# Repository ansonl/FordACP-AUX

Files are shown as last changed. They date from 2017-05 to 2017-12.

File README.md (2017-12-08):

# Ford CD changer emulator with AUX audio and stock playback control using Arduino UNO

### **Keep the retro stereo. Bring your own tunes.**

demo

Add AUX audio input to your older Ford vehicle using a Atmega328 (Arduino UNO) and use the stock radio head unit to control playback on your iPhone. 

## [Read about the development of this.](http://ansonliu.com/2017/09/ford-acp-cd-changer-emulator-aux-audio/)

  - Adapted from Dale Thomas's [*Ford Bluetooth Interface*](http://www.instructables.com/id/Ford-Bluetooth-Interface-Control-phone-with-stock-/) and Krysztof Pintscher's  [Ford CD Emulator](http://www.instructables.com/id/Ford-CD-Emulator-Arduino-Mega/).
  - Uses Ford Audio Control Protocol (ACP) to emulate stock 6 CD Changer.
  - Adds AUX audio input to vehicle.
  - Allows stock head unit playback control of iPhone.
  - Protoshield hand wiring diagram included in `Resources` folder. 
  - EAGLE PCB files in `eagle` folder.

### Directions
  - Open **Ford_ACP_AUX.ino** located in *Sketch/Ford_ACP_AUX* and upload to Arduino UNO.
  - Acquire parts on Bill of Materials located in *Resources/LIU_FORD_ACP_AUX_BOM.xlsx*.
  - Do one of the following
    1. Wire up Arduino UNO like shown below. *Note: Updated pin 8 → pin 7 in latest code.*
    2. Print PCB using provided EAGLE files.
  - Place the assembly in your car.

#### BLE vehicle lock/unlock.
  - Follow directions above but use **Ford_AUX_BLE_control.ino** located in *Sketch/Ford_AUX_BLE_control* and upload to Arduino UNO.
  - Build and install [ansonl/ble-control](https://github.com/ansonl/ble-control) on your iOS device.

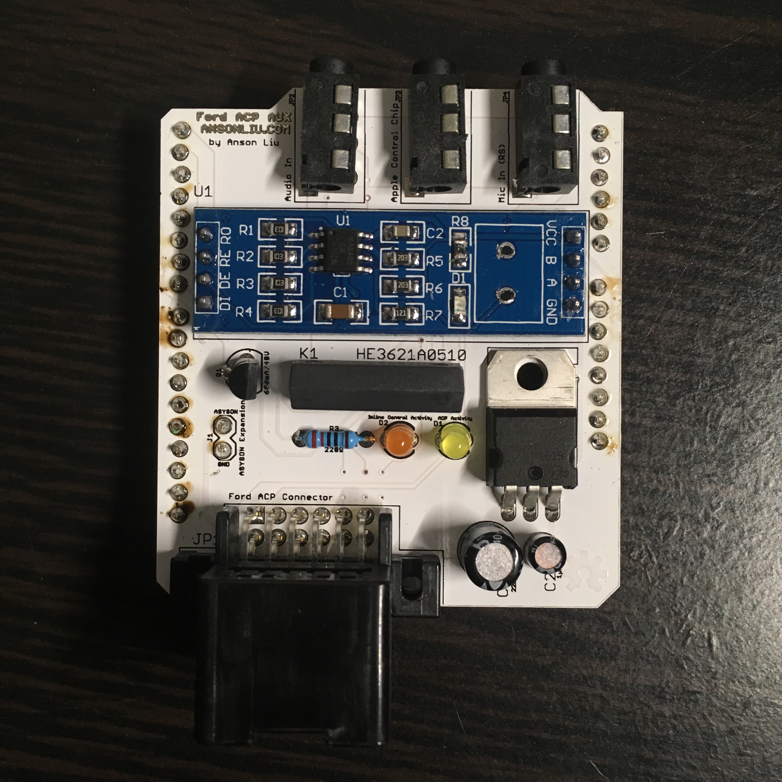
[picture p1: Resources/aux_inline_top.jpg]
PCB top

closing glovebox

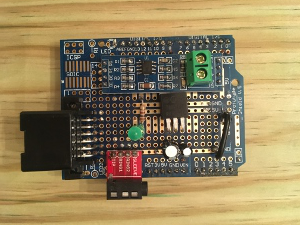
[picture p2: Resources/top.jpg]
top
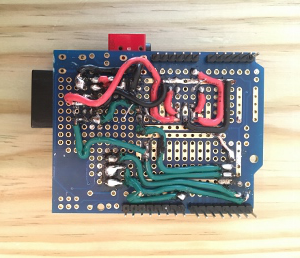
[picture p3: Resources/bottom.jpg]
bottom
 
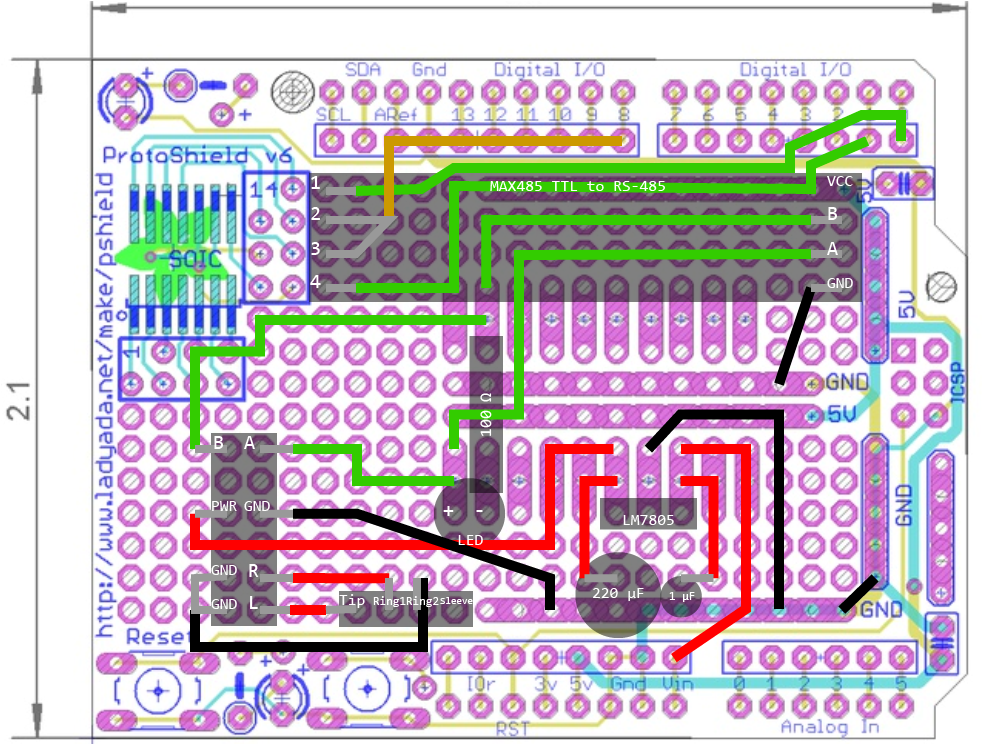
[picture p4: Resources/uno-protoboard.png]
uno protoboard

*Please note that pin 8 in the above diagram has been changed to pin 7 in the latest Ford_AUX_BLE code.* 

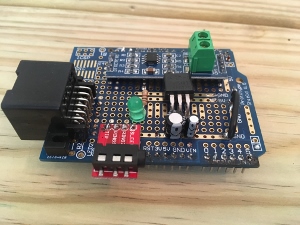
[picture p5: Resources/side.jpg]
side
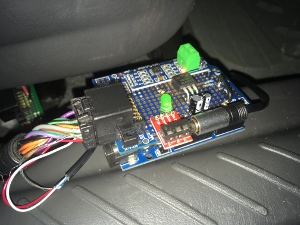
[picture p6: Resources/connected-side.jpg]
connected side
 

#### ACP Data Logging and LCD Graphing
  - Use **Ford_LCD_datagraph.ino** located in *Sketch/Ford_LCD_datagraph*.

acp visualizer

### Contributing

Please report issues and submit pull requests as needed. Please make an issue for soldering or build issues, too. 

I have resolved several people's build issues by email and someone may find your issue helpful!

### License

Any adaptation of this work must comply with licenses of previous works (those in `Resources` folder) and include references to the previous authors. 

**Any work by Anson Liu in this repository is under MIT License.**

  - Andrew Hammond
  - [Krysztof Pintscher](http://www.instructables.com/id/Ford-CD-Emulator-Arduino-Mega/)
  - [Dale Thomas](http://www.instructables.com/id/Ford-Bluetooth-Interface-Control-phone-with-stock-/)
  - [Anson Liu](http://ansonliu.com)

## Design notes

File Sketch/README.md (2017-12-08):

# See below for description of each Sketch.

####  Please note the updated pin assignments in the code before soldering.

Sketch directory | Description
--- | ---
EEPROM_test | Tests writing and reading constants in EEPROM.
**Ford_ACP_AUX** | **Standalone code for ACP CD changer emulation and inline playback control. *Latest!***
Ford_ANCS | Old sketch demonstrating ANCS integration with an LCD. Incorporates scrolling text for notifications. 
**Ford_AUX_BLE_control** | **ACP CD changer emulation and inline playback control. Use with [anson/BLE-control](https://github.com/ansonl/BLE-control). *Latest!***
Ford_LCD_datagraph | Debug sketch for graphing ACP data on a Hitachi HD44780 4x16 display. 
Ford_SD_ACP_datalogger | Debug sketch for logging ACP data to SD card using SD shield.
Ford_SD_datalogger | Debug sketch
Ford_Uno | Initial converted version of Dale Thomas' Arduino code to run on Arduino Uno.

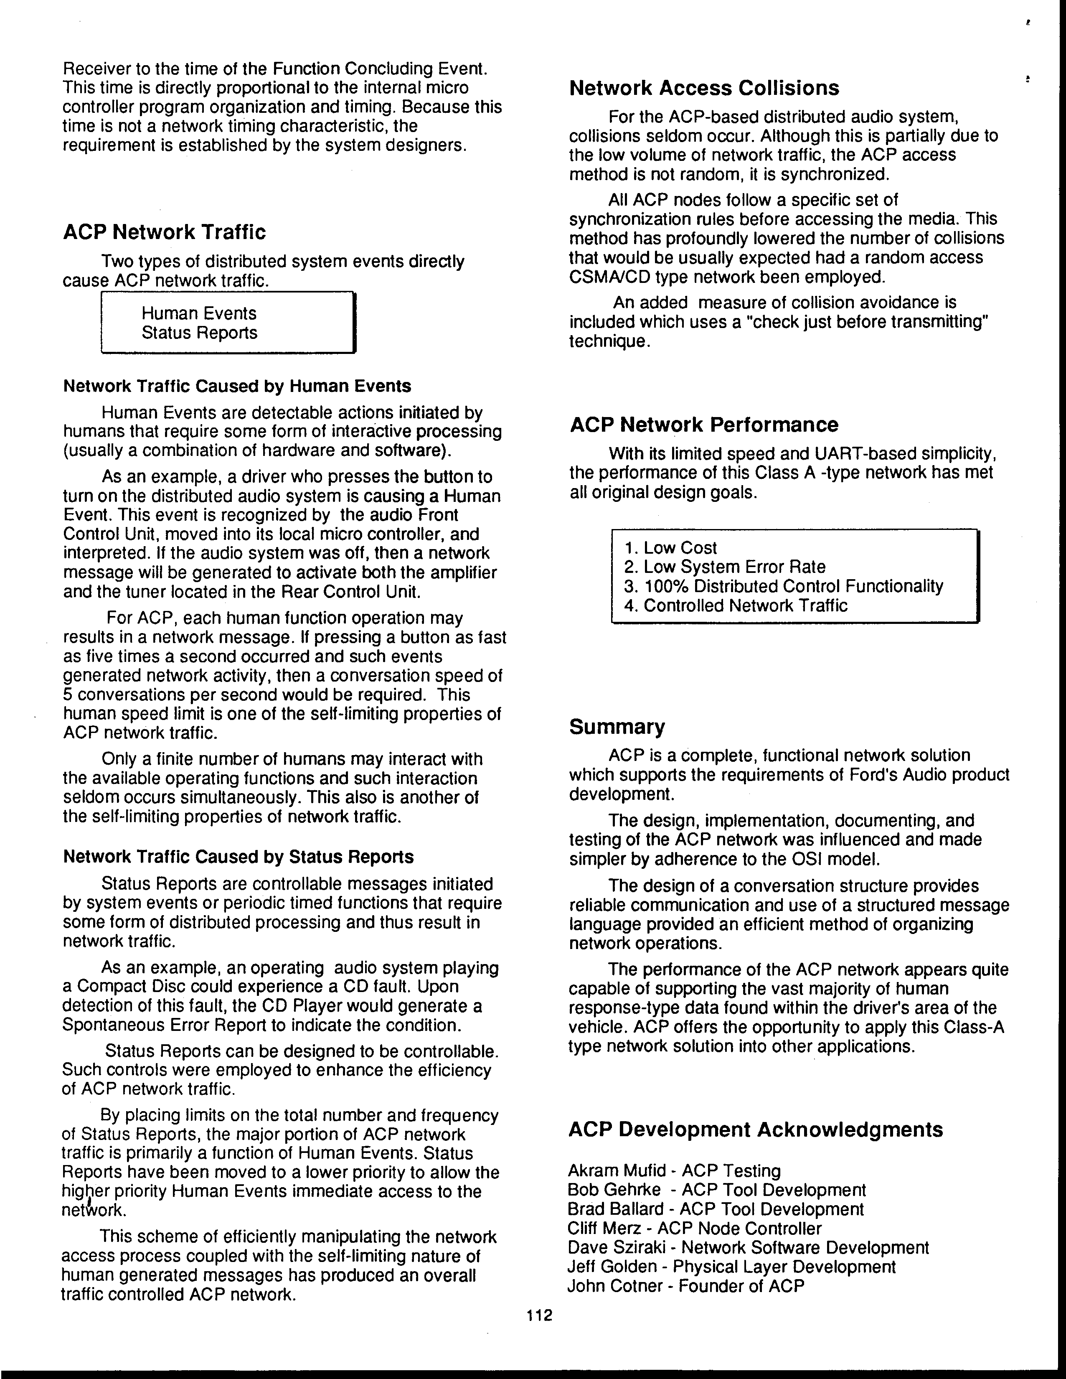
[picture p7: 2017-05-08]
Resources/Ford Bluetooth Interface V1.0 - Dale Thomas/Misc Documents/Misc Documents/Misc Documents/ACP/FORDs_ACP_Protocol/page18.bmp

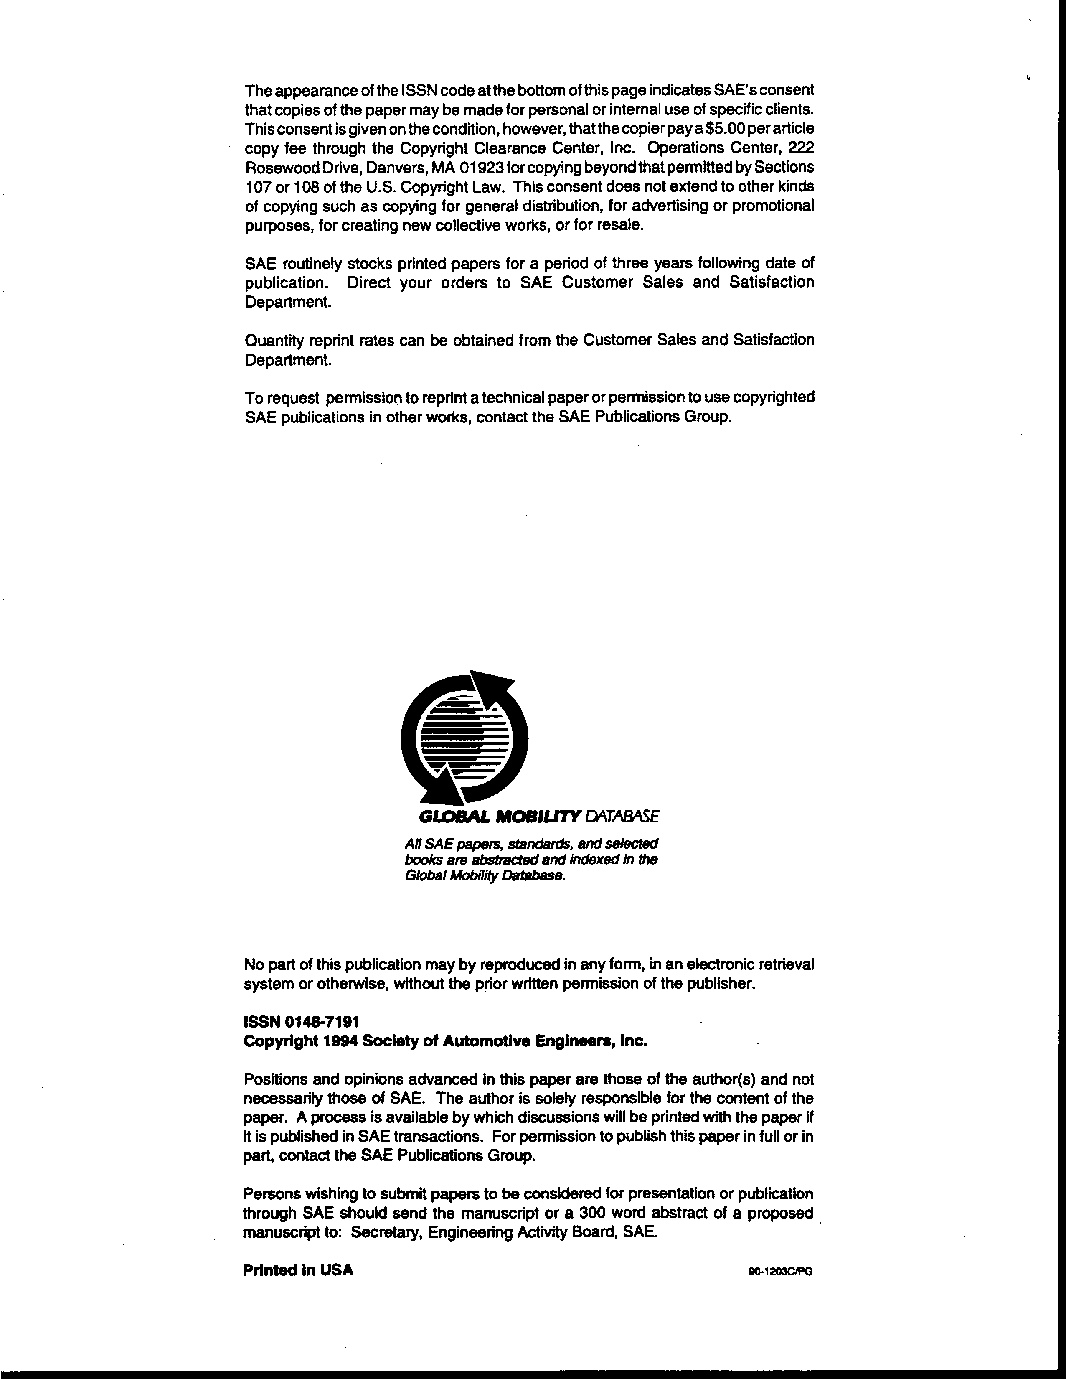
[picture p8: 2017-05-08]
Resources/Ford Bluetooth Interface V1.0 - Dale Thomas/Misc Documents/Misc Documents/Misc Documents/ACP/FORDs_ACP_Protocol/page02.bmp

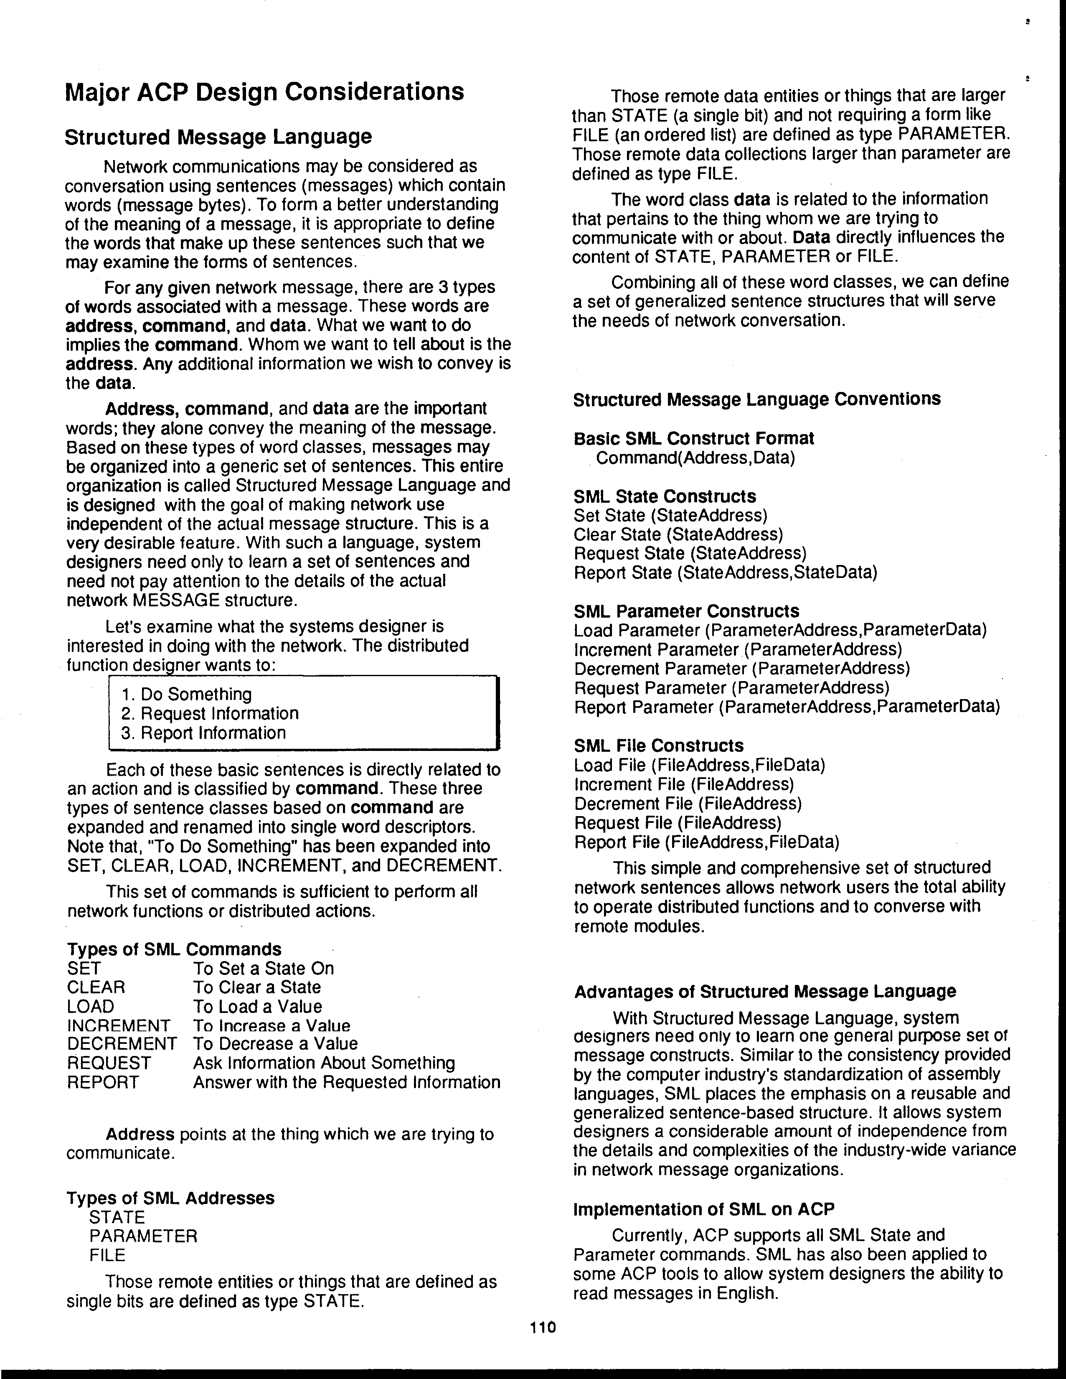
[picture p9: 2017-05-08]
Resources/Ford Bluetooth Interface V1.0 - Dale Thomas/Misc Documents/Misc Documents/Misc Documents/ACP/FORDs_ACP_Protocol/page16.bmp

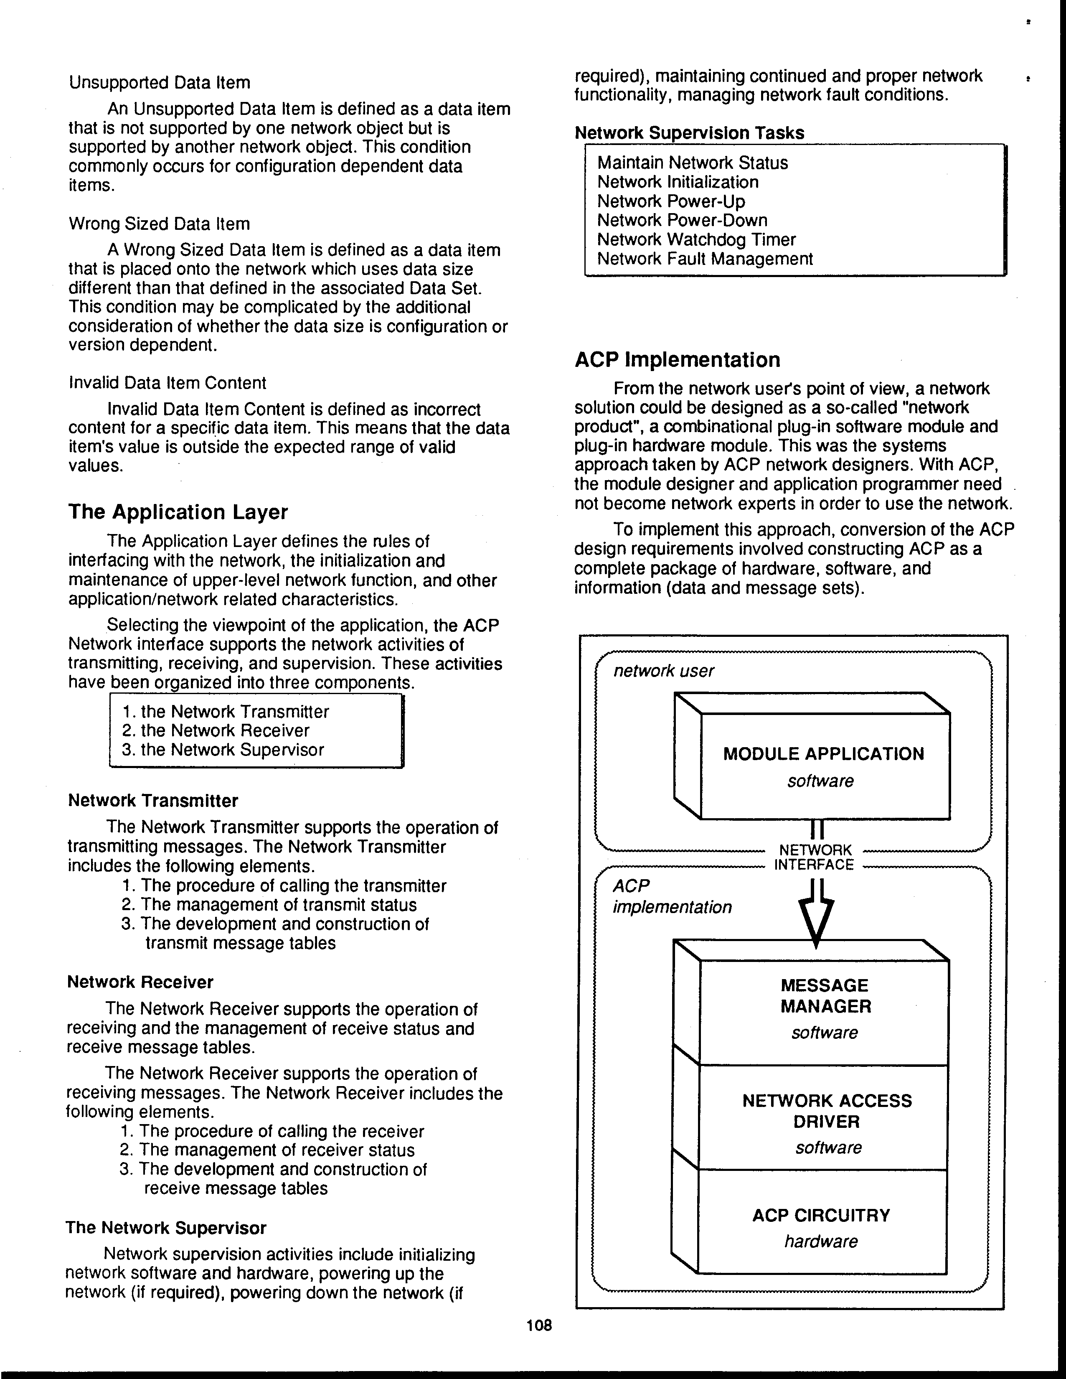
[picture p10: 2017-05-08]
Resources/Ford Bluetooth Interface V1.0 - Dale Thomas/Misc Documents/Misc Documents/Misc Documents/ACP/FORDs_ACP_Protocol/page14.bmp

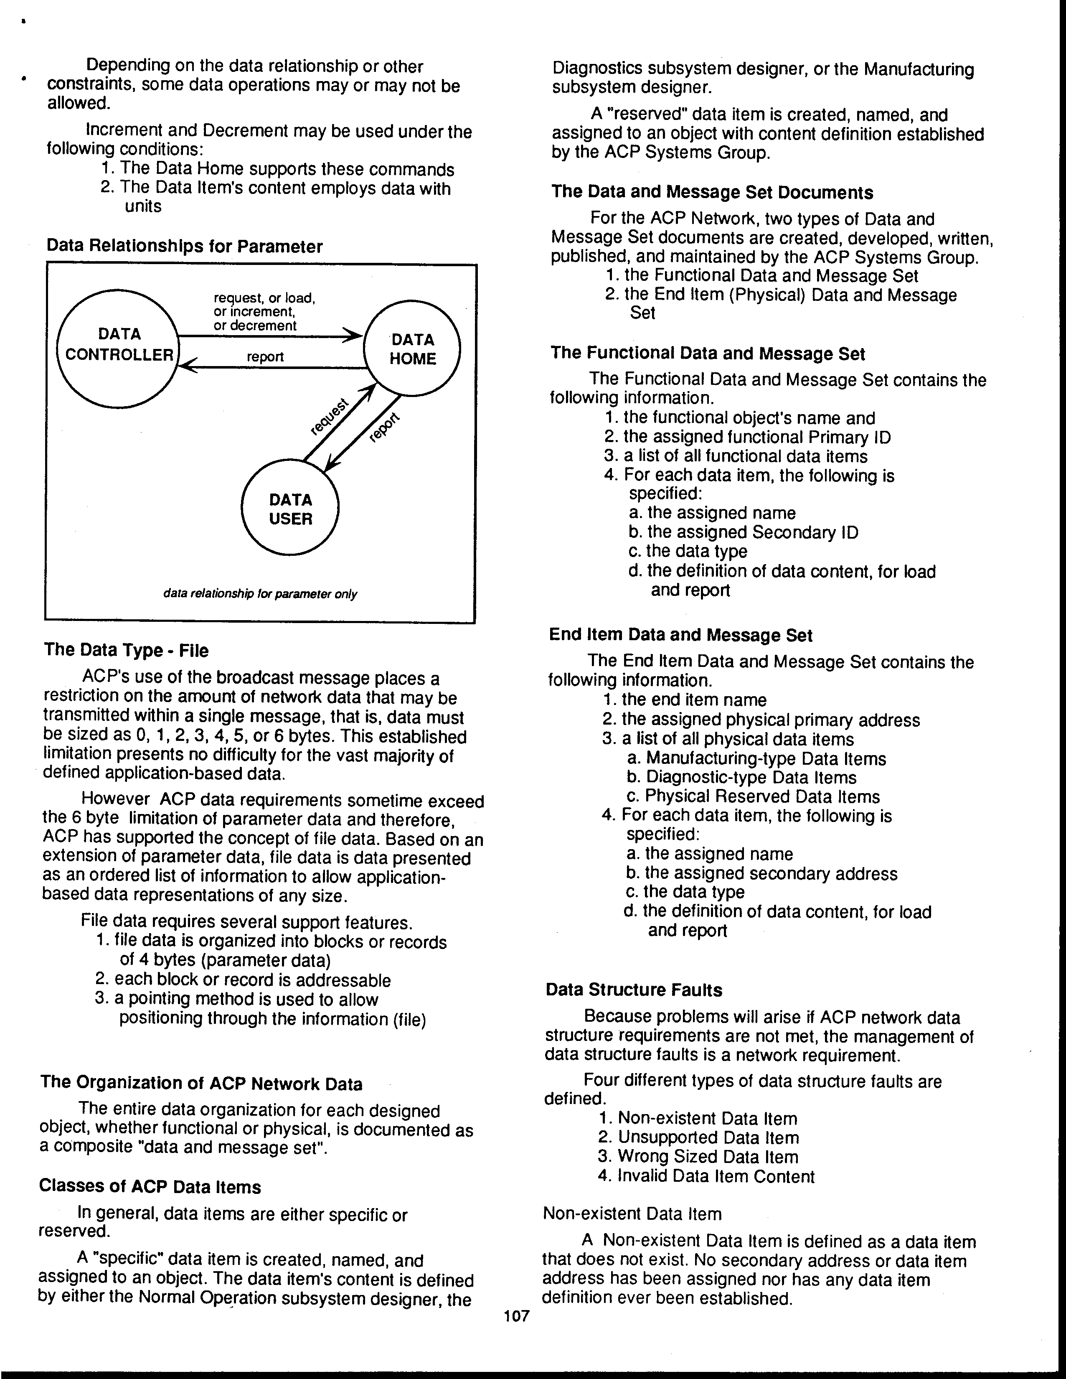
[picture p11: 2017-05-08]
Resources/Ford Bluetooth Interface V1.0 - Dale Thomas/Misc Documents/Misc Documents/Misc Documents/ACP/FORDs_ACP_Protocol/page13.bmp

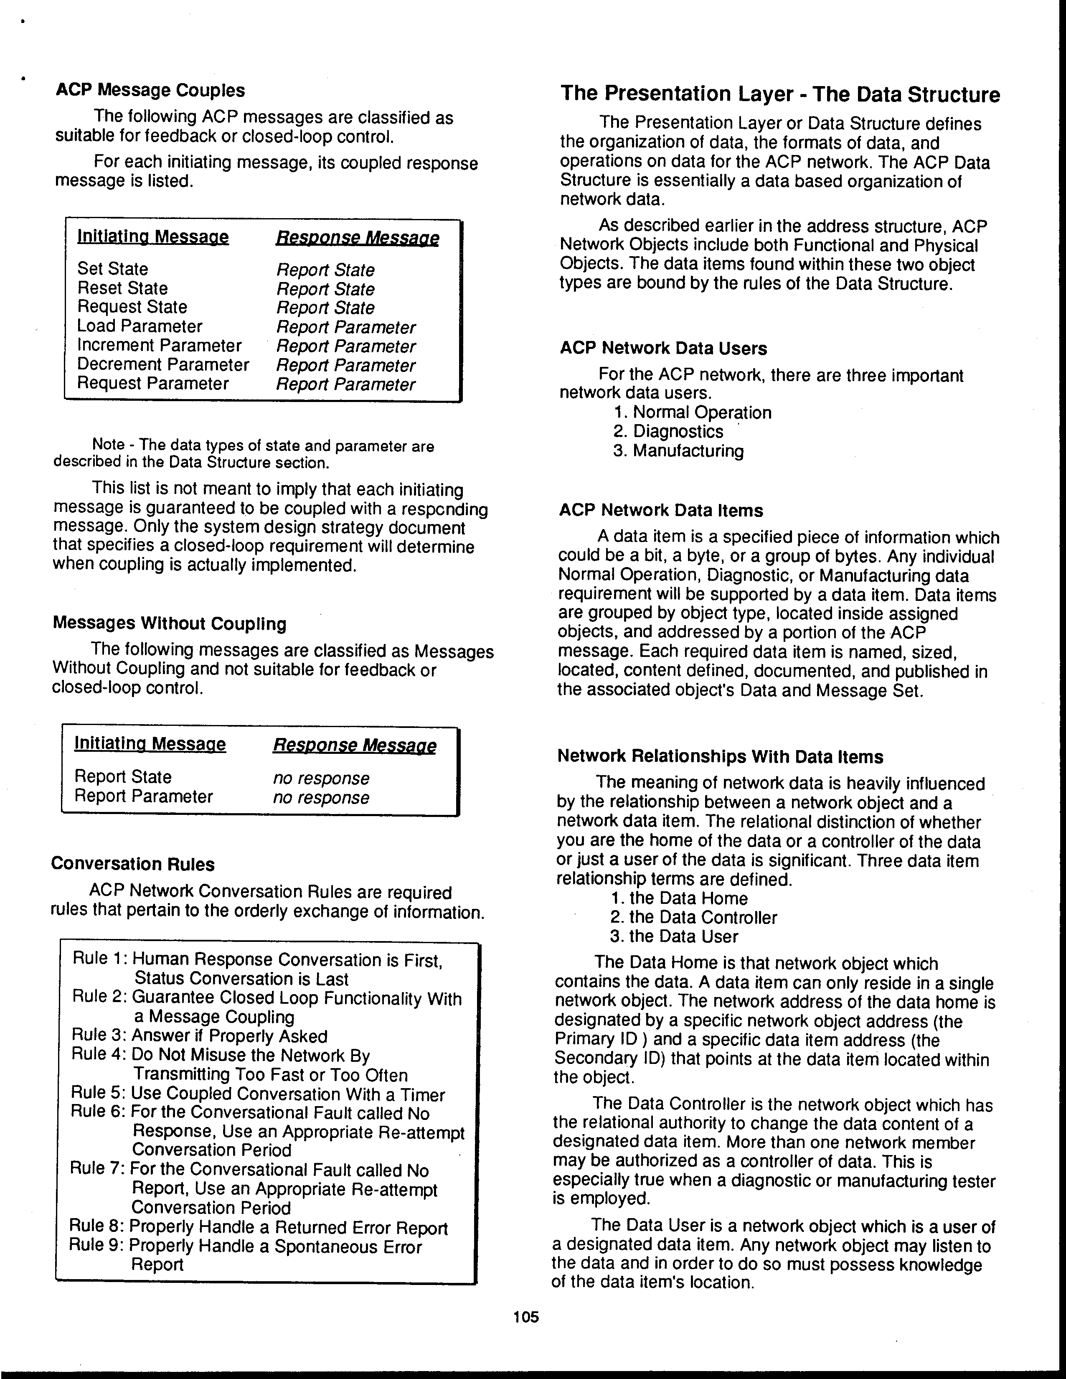
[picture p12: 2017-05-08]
Resources/Ford Bluetooth Interface V1.0 - Dale Thomas/Misc Documents/Misc Documents/Misc Documents/ACP/FORDs_ACP_Protocol/page11.bmp

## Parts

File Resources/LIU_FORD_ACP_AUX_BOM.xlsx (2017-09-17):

Alias | Description | Supplier | Suppliers Part # | Manufacturers Part # | Quantity | Cost Each | Total Cost
 | Arduino UNO | Ebay |  |  | 1 | $5.00 | $5.00
B1 | Arduino UNO size shield or Ford ACP AUX PCB | Ebay/Other |  |  | 1 | $2.00 | $2.00
 | 2.54mm Breakout board stackable headers, 12pins | Tayda |  |  | 4 | $0.22 | $0.88
JP1 | Series 40 locking connector (Female, wire-to-board) | Mouser | 571-174051-2 | 174051-2 | 1 | $5.00 | $5.00
IC1 | LM7805 5V voltage regulator | Tayda |  |  | 1 | $0.23 | $0.23
C1 | 220 uF filter capacitor, electrolytic | Tayda |  |  | 1 | $0.03 | $0.03
C2 | 1 uF filter capacitor, electrolytic | Tayda |  |  | 1 | $0.02 | $0.02
U1 | (Max485) TTL to RS485 converter breakout board | Ebay |  |  | 1 | $0.50 | $0.50
D1 | 5mm LED (ACP activity indicator) | Tayda |  |  | 1 | $0.02 | $0.02
JP1 JP2 JP3 | 3.5mm 4-pole TRRS Cellphone Headphone Jack PCB mount | mklec | 83-176-1245 | 3.5MM4POLEJACK | 3 | $0.40 | $1.20
Q1 | 2N2222 NPN transistor | Tayda |  |  | 1 | $0.02 | $0.02
K1 | LITTLEFUSE Reed relay w/ diode supressed coil | Arrow |  | HE3621A0510 | 1 | $1.00 | $1.00
R3 | 220 ohm resistor 1/4W | Tayda |  |  | 1 | $0.02 | $0.02
D2 | 5mm LED (Inline control activity indicator) | Tayda |  |  | 1 | $0.02 | $0.02
optional, for wiring | 4 Conductor Metal 3.5 Female to Female Ground Isolated Feed-thru Jack | Markertek |  | 30-707 | 1 | $4.82 | $4.82
optional, for wiring | 3.5mm TRRS cable, 3ft | Monoprice |  | 18632 | 2 | $2.00 | $4.00
optional, for wiring | Series 40 locking connector (Male, wire-to-wire) | Arrow |  | TE 174045-2 | 2 |  | $0.00
optional, for wiring | Series 40 locking connector (Female, wire-to-wire) | Arrow |  | TE 174058-2 | 1 |  | $0.00
optional, for wiring | Series 40 locking connector (For TE 174045-2) | Arrow |  | TE 175180-1 | 24 |  | $0.00
optional, for wiring | Series 40 locking connector (For TE 174058-2) | Arrow |  | TE 175182-1 | 12 |  | $0.00
 |  |  |  |  |  |  | $24.76
 |  |  |  |  |  | Total: | $0.00

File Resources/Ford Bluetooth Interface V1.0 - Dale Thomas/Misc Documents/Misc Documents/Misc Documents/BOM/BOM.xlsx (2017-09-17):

Alias | Description | Supplier | Suppliers Part # | Manufacturers Part # | Quantity | Last Cost Each | Total Cost
DIS_1 | 1602 16x2 HD44780 Character LCD Display Module LCM Yellow Blacklight | eBay |  | HD44780 | 1 | $3.33 | $3.33
MCU_1 | ATmega2560-16AU CH340G MEGA 2560 R3 Board + Free USB Cable for Arduino | eBay |  |  | 1 | $13.85 | $13.85
BLT_1 | BLK-MD-SPK-B bluetooth breakout board for the OVC 3860 | eBay |  | BLK-MD-SPK-B | 1 | $6.89 | $6.89
MIC_1 | Mini 2 Pin 53-54 DB 9.7mm*6.7mm Electret Microphone Pickup Condenser | eBay |  |  | 1 | $0.19 | $0.19
U_1 | TLP250 optical isolator | eBay |  | TLP250 | 1 | $1.00 | $1.00
U_2 | Max 485 ttl to RS485 converter | eBay |  | MAX485 | 1 | $2.20 | $2.20
U_3 | LM7805 5V voltage regulator | eBay |  | LM7805 | 1 | $0.39 | $0.39
CON_1 | Series 40 locking connector | Mouser | 571-174051-2 | 174051-2 | 1 | $2.45 | $2.45
CON_2, CON_3 | 40-Pin 2.54mm Straight Female Header | eBay |  |  | 2 | $0.10 | $0.20
CON_4 | Amico DIP PCB Mount 11 Pins Female 3.5mm Stereo Audio Jack Socket | eBay |  |  | 1 | $1.39 | $1.39
PCB_1 | Prototype PCB for Arduino Mega 2560 R3 Shield Board | eBay |  |  | 1 | $2.20 | $2.20
PCB_2 | Bluetooth BLK-MD-SPK-B Stereo Module Breakout board | eBay |  |  | 1 | $4.00 | $4.00
POT_1 | 1000 ohm potentiometer | eBay |  |  | 1 | $0.17 | $0.17
D_1 | Red LED | eBay |  |  | 1 | $0.03 | $0.03
D_2 | Blue LED | eBay |  |  | 1 | $0.03 | $0.03
D_3 | Green LED | eBay |  |  | 1 | $0.03 | $0.03
R_1, R_2 | 500 ohm resistor | eBay |  |  | 2 | $0.01 | $0.02
R_3, R_5, R_6 | 10000 ohm resistor | eBay |  |  | 3 | $0.01 | $0.03
R_4 | 2700 ohm resistor | eBay |  |  | 1 | $0.01 | $0.01
L_1 | 15 nH inductor | eBay |  |  | 1 | $0.10 | $0.10
C_1 | 4.7 uF capacitor | eBay |  |  | 1 | $0.10 | $0.10
C_2 | 10 pF capacitor | eBay |  |  | 1 | $0.10 | $0.10
C_3 | 1 uF | eBay |  |  | 1 | $0.10 | $0.10
C_4 | 220 uF filter capacitor, electrolytic | eBay |  |  | 1 | $0.10 | $0.10
C_5 | 1 uF filter capacitor, electrolytic | eBay |  |  | 1 | $0.10 | $0.10
 |  |  |  |  |  | Total: | $39.01

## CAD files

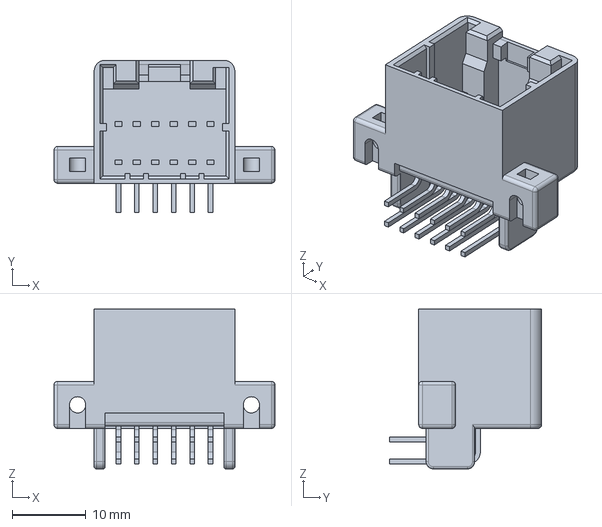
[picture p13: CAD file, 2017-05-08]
Resources/Ford Bluetooth Interface V1.0 - Dale Thomas/Misc Documents/Misc Documents/Misc Documents/Radio Connectors/Connectors/c-174051-2-k-3d.stp
30.0 x 20.7 x 21.7 mm

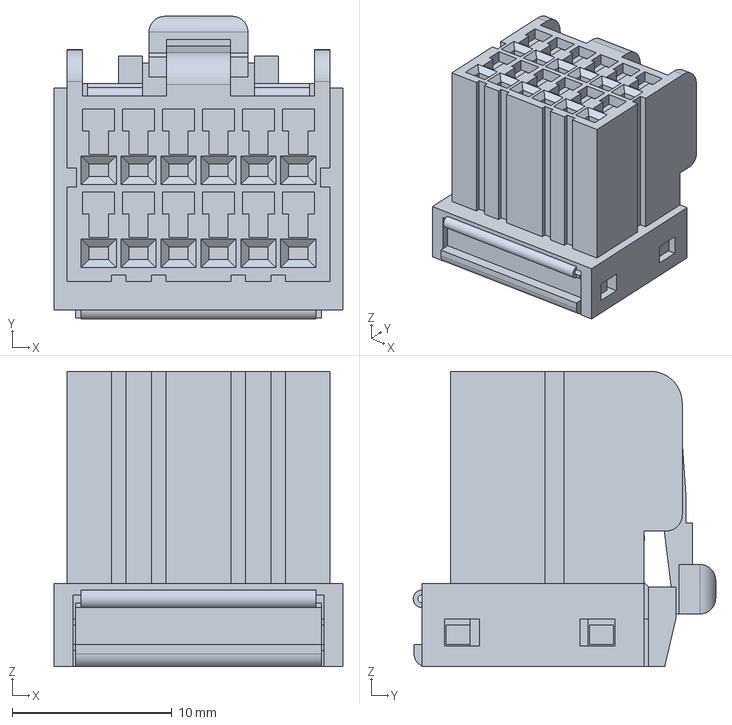
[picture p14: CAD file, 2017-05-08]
Resources/Ford Bluetooth Interface V1.0 - Dale Thomas/Misc Documents/Misc Documents/Misc Documents/Radio Connectors/Connectors/c-174045-2-c1-3d.stp
18.1 x 19.0 x 18.5 mm

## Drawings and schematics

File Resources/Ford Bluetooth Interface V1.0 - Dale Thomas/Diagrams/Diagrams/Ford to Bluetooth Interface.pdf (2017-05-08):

# Ford Bluetooth Interface

V 1.0

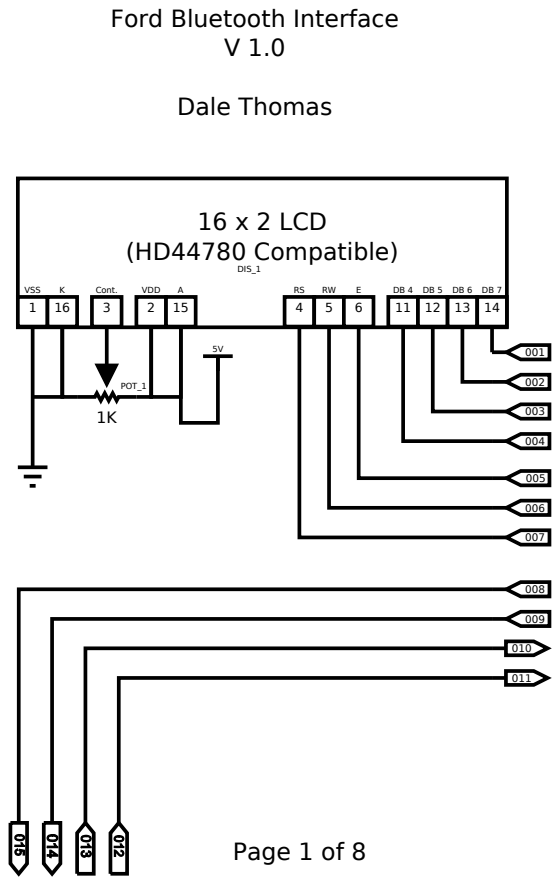
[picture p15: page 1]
VSS; VDDCont.; 16 x 2 LCD (HD44780 Compatible); Page 1 of 8; Dale Thomas; DIS_1; POT_1

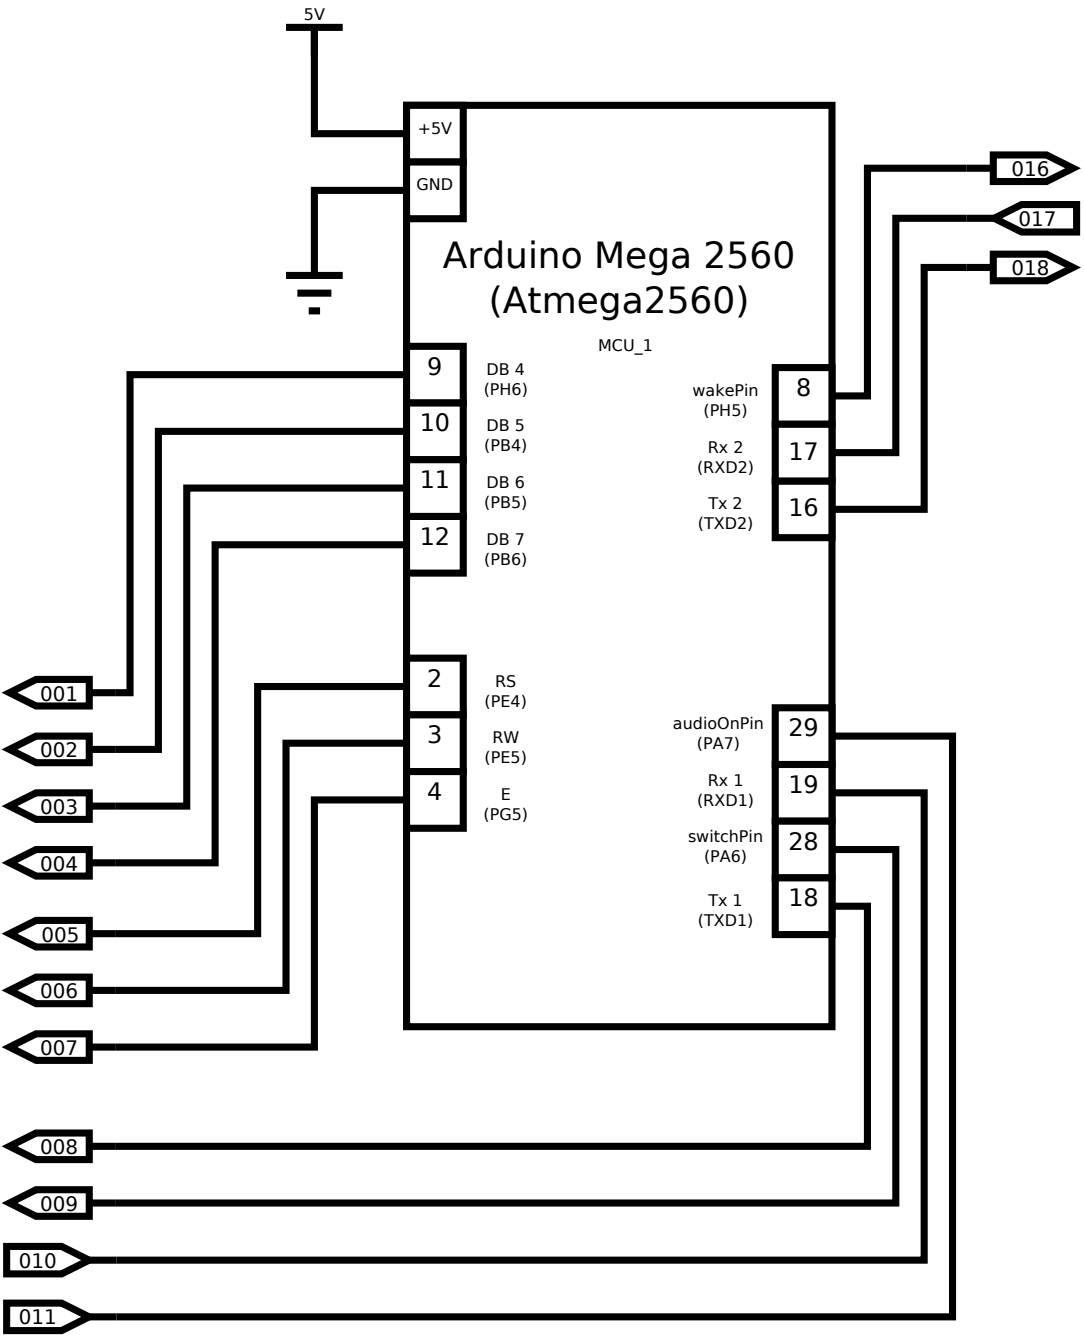
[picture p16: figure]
wakePin (PH5); switchPin; audioOnPin; Tx 2 (TXD2); Rx 2 (RXD2); (TXD1); (RXD1); Arduino Mega 2560 (Atmega2560); GND; MCU_1

# Page 2 of 8

016

017

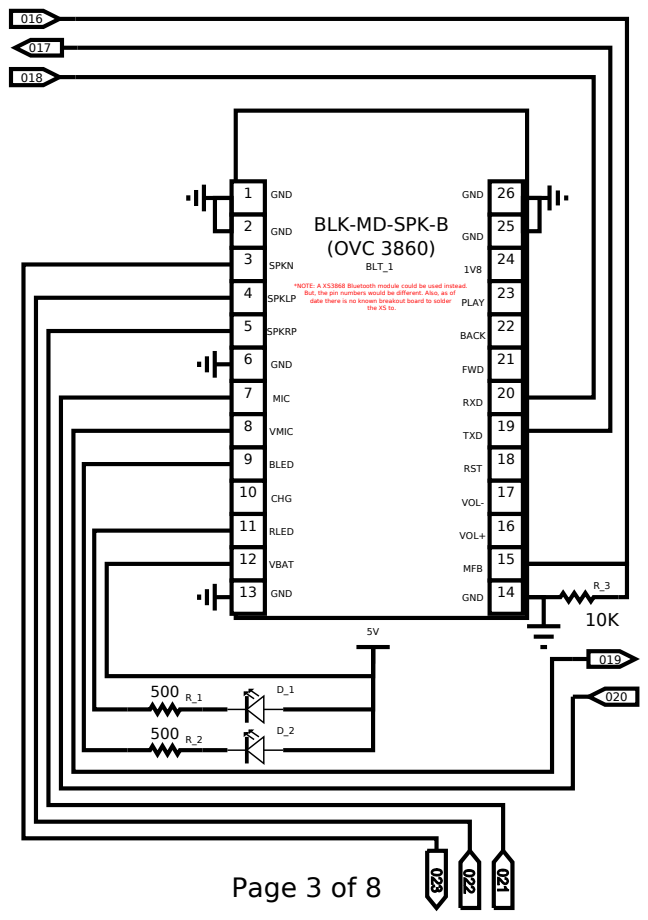
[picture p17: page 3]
1 GND; 2 GND; 3 SPKN; 4 SPKLP; 5 SPKRP; 6 GND; MIC; 8 VMIC; 9 BLED; 10 CHG; 11 RLED; 12 VBAT; 13 GND; GND; PLAY; BACK; FWD; RXD; TXD; RST; VOL-; VOL+; MFB; Page 3 of 8; BLT_1

BLK-MD-SPK-B
(OVC 3860)

*NOTE: A XS3868 Bluetooth module could be used instead.
But, the pin numbers would be different. Also, as of
date there is no known breakout board to solder

the XS to.

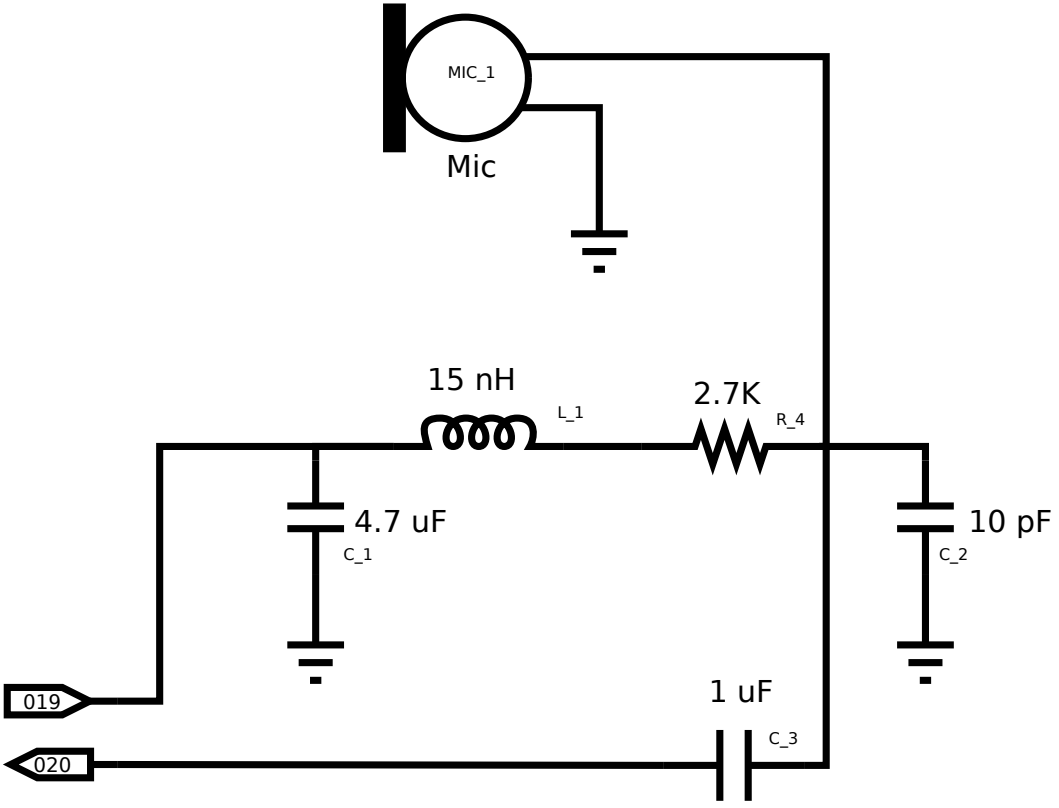
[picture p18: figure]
Mic; MIC_1

# Page 4 of 8

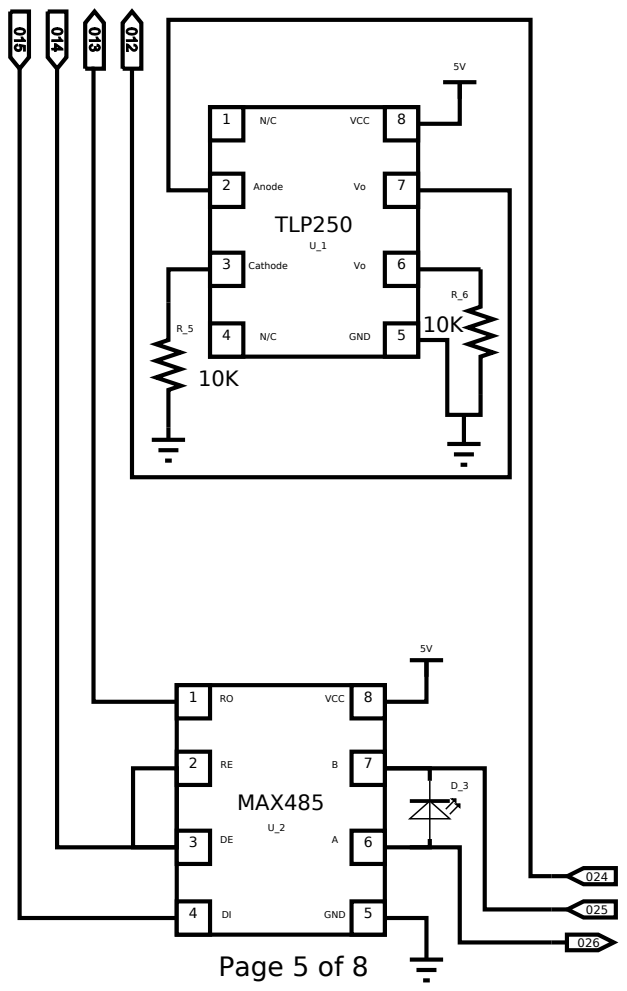
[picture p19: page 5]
VCC; GND; 3 Cathode; Anode; TLP250; MAX485; Page 5 of 8

LM7805

IN | OUTGND
5V
1 | 2 | 3

# Page 6 of 8

024

025

026

027

028

029

030

# 220 uF 1 uF

U_3

C_4 | C_5

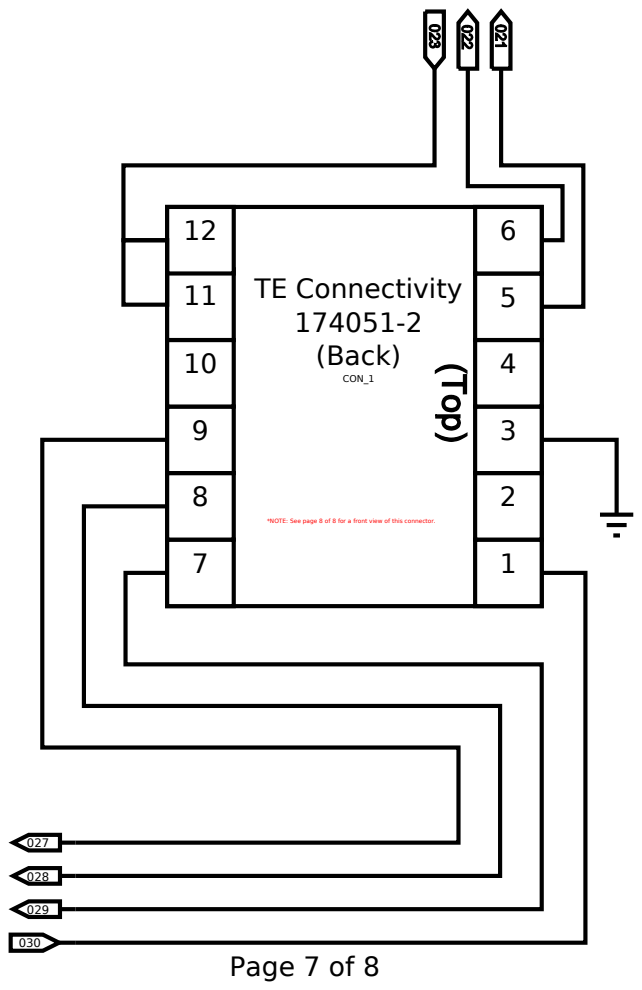
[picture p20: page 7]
TE Connectivity 174051-2 (Back); Page 7 of 8; CON_1

*NOTE: See page 8 of 8 for a front view of this connector.

# TE Connectivity

174051-2

# (Front)

1 | 2 | 3 | 4 | 5 | 6
7 | 8 | 9 | 10 | 11 | 12

# (Top)

# Page 8 of 8

CON_1

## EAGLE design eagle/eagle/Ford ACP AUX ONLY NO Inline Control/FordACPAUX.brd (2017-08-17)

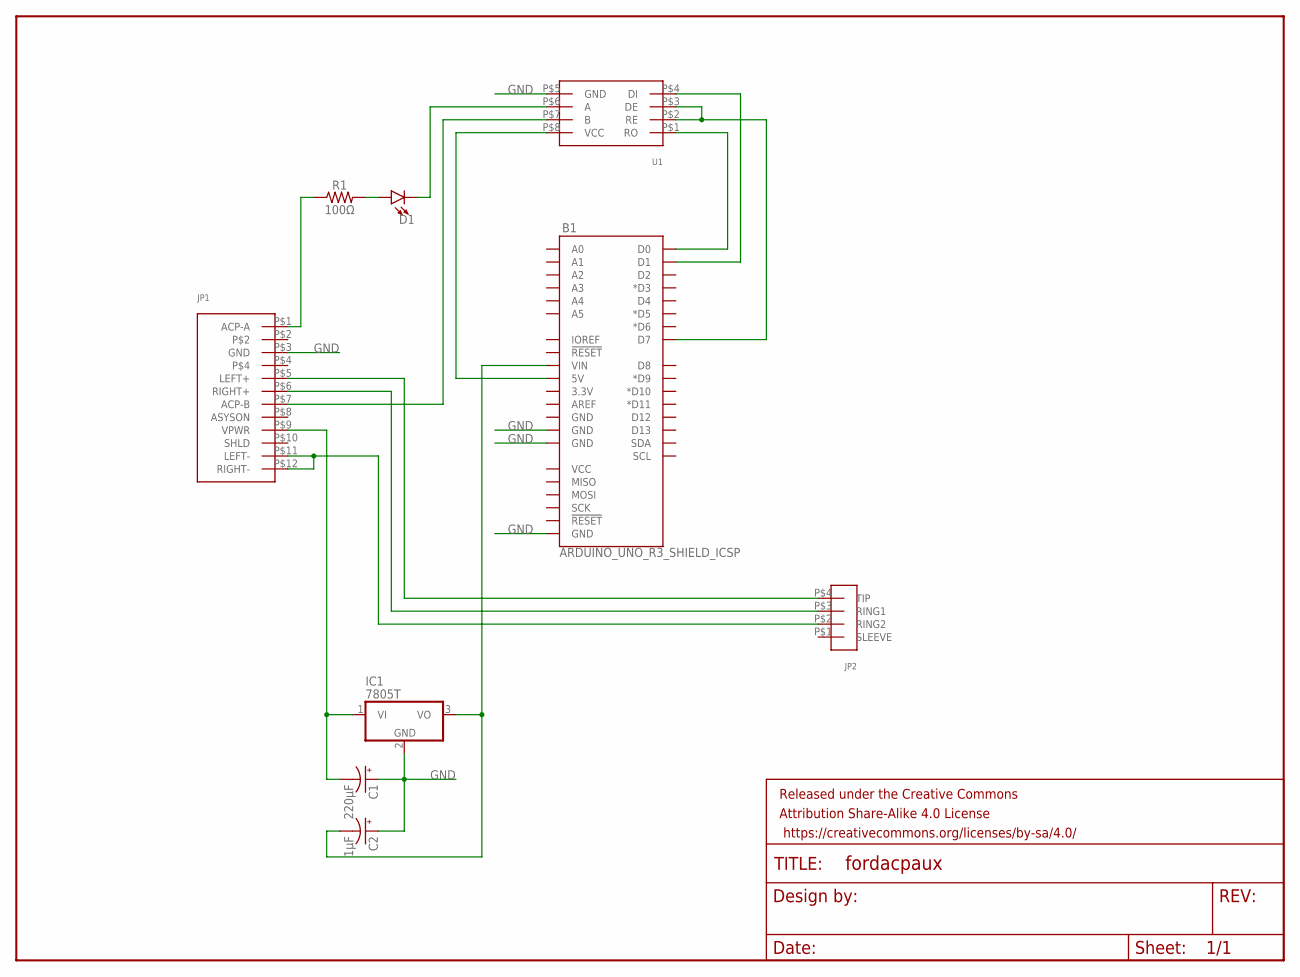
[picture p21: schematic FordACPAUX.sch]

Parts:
B1: ARDUINO_UNO_R3_SHIELD_ICSP; UNO_R3_SHIELD_ICSP
C1: 220μF; E2,5-7
C2: 1μF; E2-4
D1: LED3MM; LED_3MM
FRAME1: FRAME-LETTER; CREATIVE_COMMONS
IC1: 7805T; TO220H
JP1: AMP-174051-2_040_MULTILOCK; AMP_174051-2_040_MULTILOCK
JP2: TRRS_JACKBREAKOUT; HEADER-4-PIN-TRRS-JACK-BREAKOUT
R1: 100Ω; AXIAL-0.3
U1: MAX485_TTL_TO_RS_485_MODULE

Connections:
GND: B1.GND@0 (GND), B1.GND@1 (GND), B1.GND_ICSP (GND), C1.+, C2.+, IC1.2 (GND), JP1.P$3 (GND), U1.P$5 (GND)
unnamed: JP1.P$1 (ACP-A), R1.P$1 (1)
unnamed: JP1.P$7 (ACP-B), U1.P$7 (B)
unnamed: D1.A, R1.P$2 (2)
unnamed: D1.K (C), U1.P$6 (A)
unnamed: C1.-, IC1.1 (VI), JP1.P$9 (VPWR)
unnamed: B1.5V, U1.P$8 (VCC)
unnamed: B1.D7, U1.P$2 (RE), U1.P$3 (DE)
unnamed: B1.RX (D0), U1.P$1 (RO)
unnamed: B1.TX (D1), U1.P$4 (DI)
unnamed: JP1.P$5 (LEFT+), JP2.P$4 (TIP)
unnamed: JP1.P$6 (RIGHT+), JP2.P$3 (RING1)
unnamed: JP1.P$11 (LEFT-), JP1.P$12 (RIGHT-), JP2.P$2 (RING2)
unnamed: B1.VIN, C2.-, IC1.3 (VO)

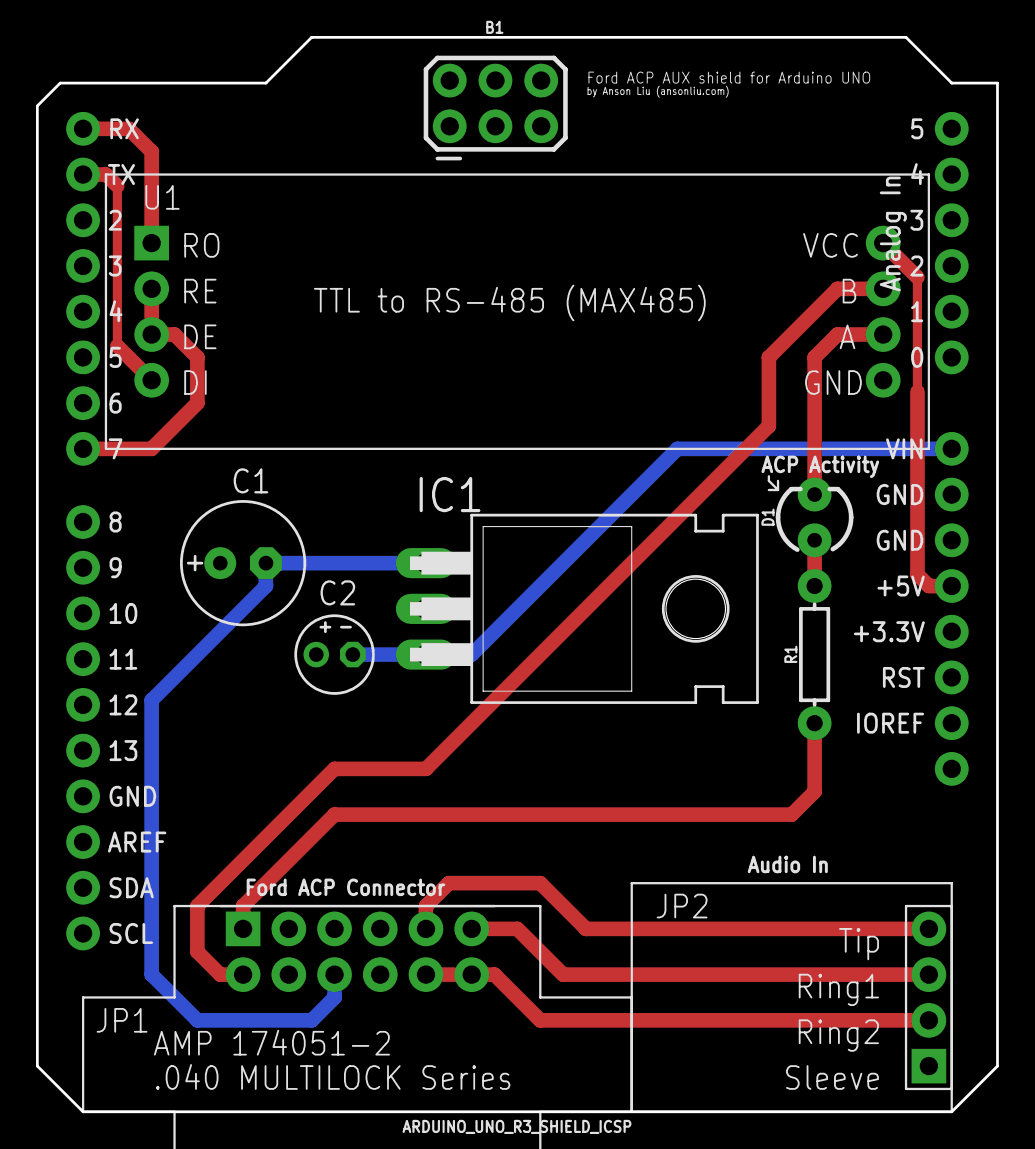
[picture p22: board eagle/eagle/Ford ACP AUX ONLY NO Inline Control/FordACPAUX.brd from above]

Board: 2 copper layers, 53.3 x 59.7 mm, 10 parts (0 on the bottom side), 14 nets.

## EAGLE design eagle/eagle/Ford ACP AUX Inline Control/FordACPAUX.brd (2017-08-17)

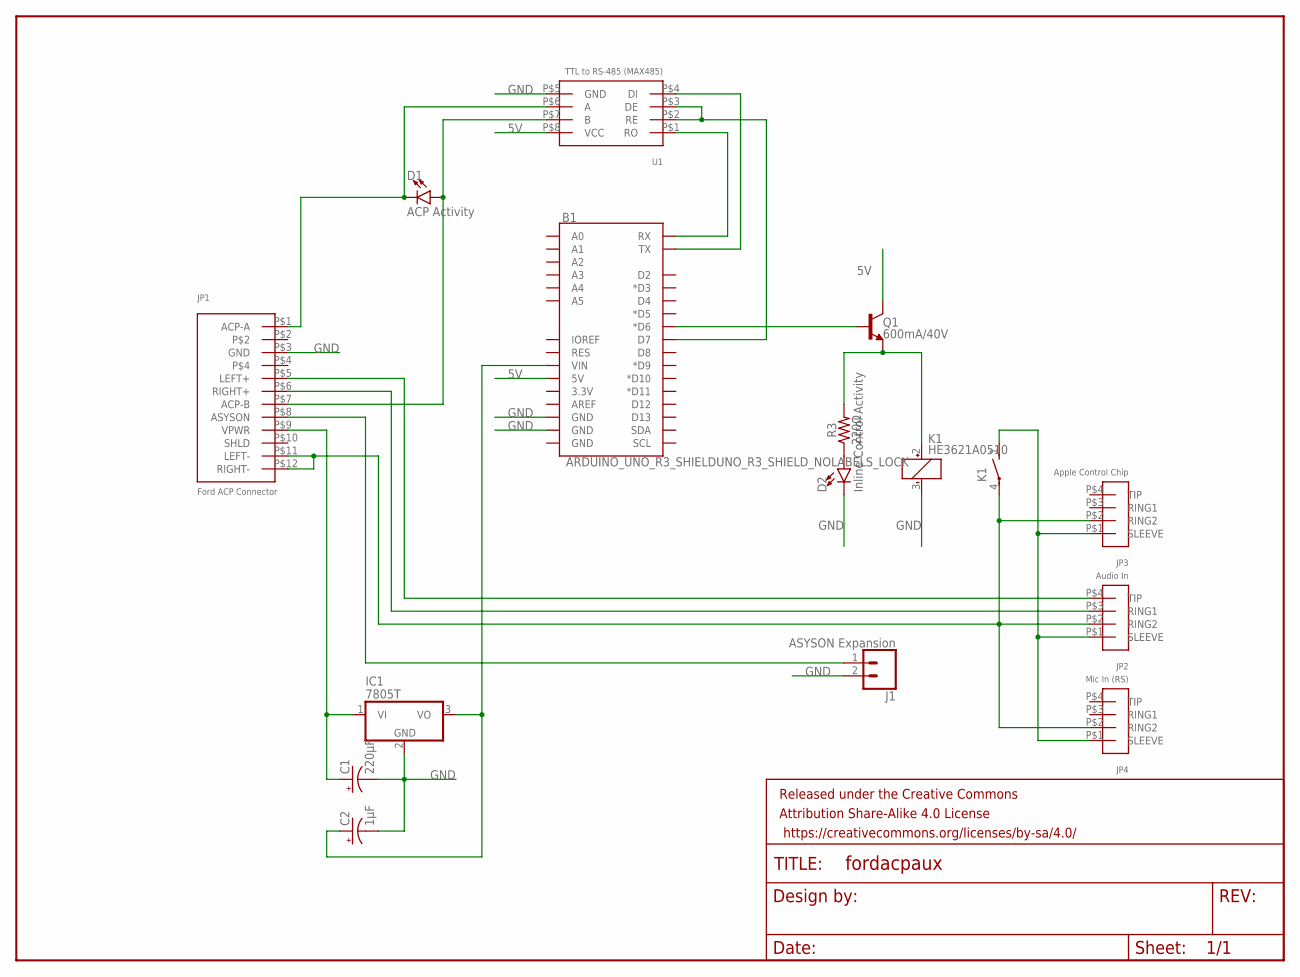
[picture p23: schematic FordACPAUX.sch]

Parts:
B1: ARDUINO_UNO_R3_SHIELDUNO_R3_SHIELD_NOLABELS_LOCK; UNO_R3_SHIELD_NOLABELS_LOCK
C1: 220μF; E2,5-7
C2: 1μF; E2-4
D1: ACP Activity; LED_3MM
D2: Inline Control Activity; LED_3MM
FRAME1: FRAME-LETTERNO_PACKAGE; DUMMY
IC1: 7805T; TO220H
J1: ASYSON Expansion; 1X02_LOCK
JP1: Ford ACP Connector; AMP_174051-2_040_MULTILOCK
JP2: Audio In; 3-5MM_4_POLE_TRRS_PCB_MOUNT
JP3: Apple Control Chip; 3-5MM_4_POLE_TRRS_PCB_MOUNT
JP4: Mic In (RS); 3-5MM_4_POLE_TRRS_PCB_MOUNT
K1: HE3621A0510; HE3621
Q1: 600mA/40V; TO-92
R3: 220Ω; AXIAL-0.3
U1: TTL to RS-485 (MAX485); MAX485_TTL_TO_RS_485_MODULE

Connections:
5V: B1.5V, Q1.1 (C), U1.P$8 (VCC)
GND: B1.GND@1 (GND), B1.GND@2 (GND), C1.-, C2.-, D2.K (C), IC1.2 (GND), J1.2, JP1.P$3 (GND), K1.3 (-), U1.P$5 (GND)
unnamed: D1.A, JP1.P$7 (ACP-B), U1.P$7 (B)
unnamed: D1.K (C), JP1.P$1 (ACP-A), U1.P$6 (A)
unnamed: C1.+, IC1.1 (VI), JP1.P$9 (VPWR)
unnamed: B1.D6 (*D6), Q1.2 (B)
unnamed: B1.D7, U1.P$2 (RE), U1.P$3 (DE)
unnamed: K1.2 (+), Q1.3 (E), R3.P$2 (2)
unnamed: B1.RX, U1.P$1 (RO)
unnamed: B1.TX, U1.P$4 (DI)
unnamed: JP1.P$5 (LEFT+), JP2.P$4 (TIP)
unnamed: JP1.P$6 (RIGHT+), JP2.P$3 (RING1)
unnamed: JP1.P$11 (LEFT-), JP1.P$12 (RIGHT-), JP2.P$2 (RING2), JP3.P$2 (RING2), JP4.P$2 (RING2), K1.4
unnamed: JP2.P$1 (SLEEVE), JP3.P$1 (SLEEVE), JP4.P$1 (SLEEVE), K1.1 (S)
unnamed: B1.VIN, C2.+, IC1.3 (VO)
unnamed: D2.A, R3.P$1 (1)
unnamed: J1.1, JP1.P$8 (ASYSON)

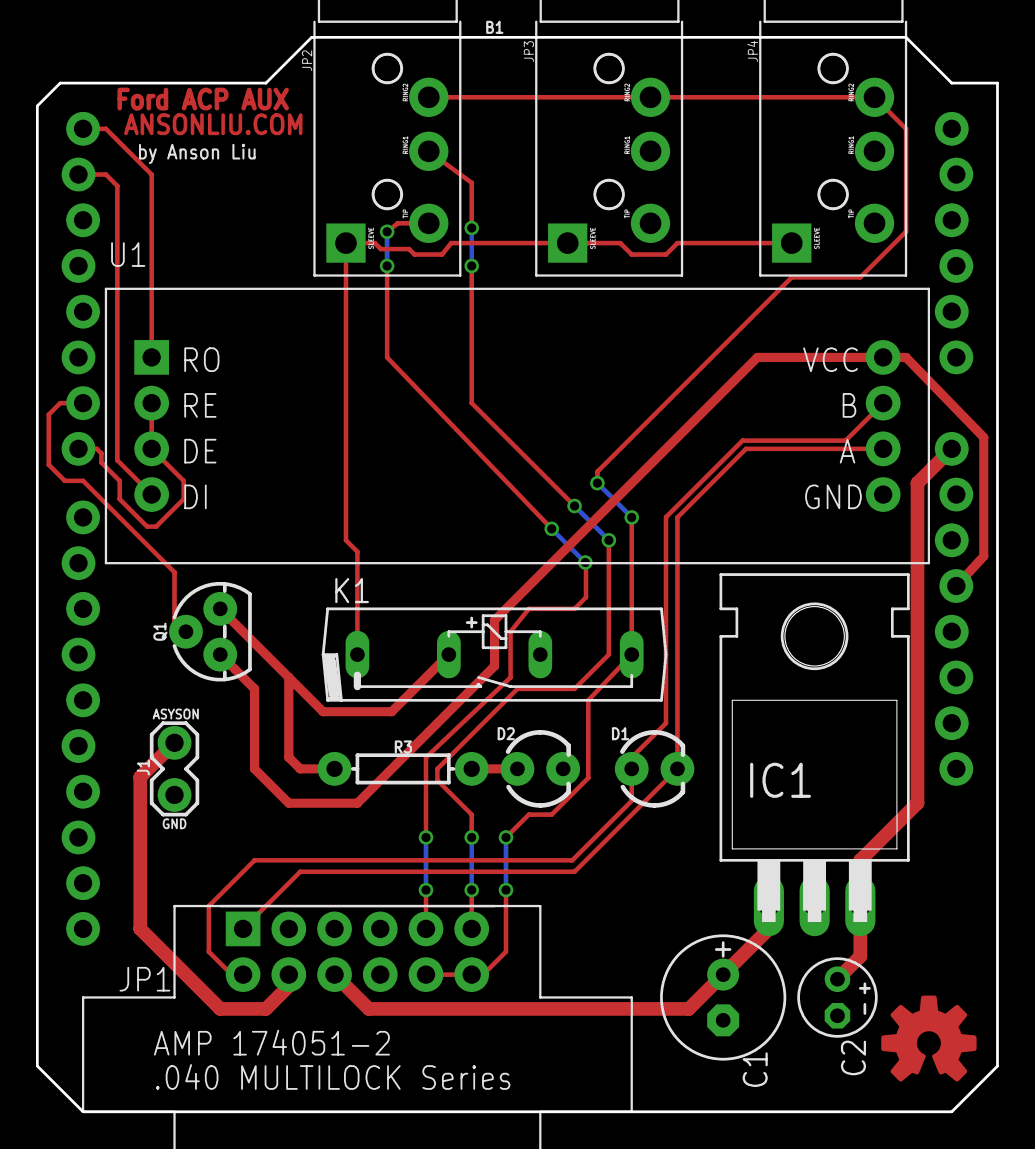
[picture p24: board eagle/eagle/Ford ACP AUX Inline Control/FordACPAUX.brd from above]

Board: 2 copper layers, 53.3 x 59.7 mm, 17 parts (0 on the bottom side), 17 nets.

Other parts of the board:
U$1: OSHWLOGO_TOP_0.2

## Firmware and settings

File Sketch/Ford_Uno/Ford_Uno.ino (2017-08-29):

/* 
 * Ford Head Unit to iOS AUX Interface v1.2
 *
 * The code in this file is intended to be uploaded to an Arduino Mega2560
 * used in combination with a specialized shield that contains the hardware
 * needed to interface with a Ford head unit and iOS TRRS audio port.
 *
 * Compatible Ford Head Units: Any unit that uses ACP (Automotive Communication
 *                             Protocol) and has a connector for a CD changer.
 *
 *                             Info on ACP:
 *                             http://www.mictronics.de/projects/cdc-protocols/#FordACP
 *                             
 *                             Some examples are:
 *                             4050RDS, 4500, 4600RDS, 5000RDS, 5000RDS EON, 
 *                             6000CD RDS, 6000 MP3, 7000RDS
 *
 *                             These are all head units from the '96 - '05 era.
 *
 *                             The unit used during testing is a 1W1F-18C870-DA 02 03
 *                             from a '99 Ford Expedition.
 *
 * The code for the ACP protocol was originally written by Andrew Hammond for his Yampp
 * and was ported over to the Arduino platform by Krzysztof Pintscher. Please see the 
 * ACP and CD headers for more info.
 *
 * Version 1.2 has been tested to be working with 2007 Ford Escape Hybrid audio system.
 *
 **************************************************************************************
 * Revisions:
 *
 * 2014-11-30 version 1.0 - public release - Dale Thomas
 * 2017-05-07 version 1.1 - Removed Bluetooth functionality and edited ports for use with Arduino UNO. - AL
 * 2017-06-16 version 1.2 - Added iOS AUX inline control commands and timing to loop(). - Anson Liu (ansonliu.com)
 *
 **************************************************************************************
 * Requirements:
 *
 * -TimerOne library
 *
 */


//BLE Control
#include <Shifty.h>
#include <AltSoftSerial.h>
#include <EEPROM.h>

#define connectionCategory 1
#define connectionValidatePassCommand 1
#define connectionSetPassCommand 2
const uint8_t eepromHeader[] = {
  1,
  6,
  3,
  8,
  7,
  6
};
uint8_t passphrase[] = {
  1,
  1,
  1,
  2
};

#define securityCategory 2
#define securityLockCommand 1
#define securityUnlockCommand 2
#define alarmCommand 3
AltSoftSerial bleSerial(2,3);
Shifty shift;
const uint8_t shiftRegisterEnablePin = 17;
const uint8_t lockPin = 0;
const uint8_t unlockPin = 1;
const uint8_t alarmPin = 2;

//Ford ACP
#include <util/delay.h>
#include <TimerOne.h>
typedef unsigned char u08;
typedef unsigned short u16;
typedef unsigned long  u32;

enum InlineControlCommand {
  noCommand,
  cancelCommand,
  playPause,
  nextTrack,
  prevTrack,
  fastForwardTrack,
  rewindTrack,
  activateSiri
};

#ifndef cbi // "clear bit"
 #define cbi(sfr, bit) (_SFR_BYTE(sfr) &= ~_BV(bit))
#endif
#ifndef sbi // "set bit"
 #define sbi(sfr, bit) (_SFR_BYTE(sfr) |= _BV(bit))
#endif
#define outp(VAL,ADRESS) ((ADRESS) = (VAL))
#define inp(VAL) (VAL)

#define ACP_UART_BAUD_RATE 	9600
#define ACP_UART_BAUD_SELECT ((u32)((u32)16000000/(ACP_UART_BAUD_RATE*16L)-1))
#define ACP_LISTEN 0
#define ACP_SENDACK 1
#define ACP_MSGREADY 2
#define ACP_WAITACK 3
#define ACP_SENDING 4

const uint8_t switchPin = 7; // Pin 7 connected to pins 2 & 3 (RE/DE) on MAX485
const uint8_t inlineControlPin = 6; // Pin 6 connected to transistor for inline control

uint8_t acp_rx[12];
uint8_t acp_tx[12];
uint8_t acp_rxindex;
uint8_t acp_txindex;
u08 acp_status;
u08 acp_txsize;
u08 acp_timeout;
u08 acp_checksum;
u08 acp_retries;
u08 acp_mode;
uint16_t acp_ltimeout;
boolean rewindState = false;
boolean ffState = false;
boolean wPlayTime = false;
uint8_t currentTrack = 1;
boolean reset_timer = false;

InlineControlCommand lastCommand;

/*
 * Write passphrase to EEPROM. Writes one byte after the EEPROM Header. Separated from EEPROM Header by one byte of value 0x0. Ends with a byte of value 0x0.
 */
void writePassToEEPROM() {
  for (uint8_t i = sizeof(eepromHeader)+1; i < sizeof(eepromHeader)+sizeof(passphrase)+1; i++)
    EEPROM.write(i, passphrase[i-sizeof(eepromHeader)]);
  EEPROM.write(sizeof(eepromHeader)+sizeof(passphrase)+1, 0x00);
}

/*
 * Write EEPROM Header at beginning of EEPROM. Write 0x00 byte after header.
 */
void writeHeaderToEEPROM() {
  for (uint8_t i = 0; i < sizeof(eepromHeader); i++)
    EEPROM.write(i, eepromHeader[i]);
  EEPROM.write(sizeof(eepromHeader), 0x00);
}

/*
 * Read passphrase from EEPROM
 */
bool readPassFromEEPROM() {
  uint8_t passLength = 0;
  while (EEPROM.read(sizeof(eepromHeader)+1+passLength) != 0x00) {
    passLength++;
  }

  passphrase[passLength];
  for (uint8_t i = 0; i < passLength; i++) {
    passphrase[i] = EEPROM.read(sizeof(eepromHeader)+1+i);
  }
}

/*
 * Reset all EEPROM to 0xff (255). 0xff (255) is the default eeprom value.
 */
void resetEEPROM() {
  for (int i = 0; i < EEPROM.length(); i++) {
    EEPROM.write(i, 0xff); 
  }
}

/*
 * Check for valid EEPROM Header at beginning of EEPROM.
 */
bool checkValidEEPROMHeader() {
  for (uint8_t i = 0; i < sizeof(eepromHeader); i++) {
    if (EEPROM.read(i) != eepromHeader[i])
      return false;
  }
  return true;
}

bool checkValidPass(char* pass) {
  readPassFromEEPROM();

  bool match = true;
  for (uint8_t j = 0; j < sizeof(passphrase); j++) {
    if (passphrase[j] != atoi(&pass[j*2])) {
      match = false;
      break;
    }
  }

  return match;
}

/*
 * Check BLE Characteristic for HM-10 BLE Module and process any commands. 
 */
void checkBLECharacteristic() {
  char command[100];
  memset(command, 0, sizeof(command));

  uint8_t i = 0;
  while (bleSerial.available()) {
    command[i] = bleSerial.read();
    command[i+1] = '\0';
    i += 2;
  }
  if (i) {
    int first = atoi(command);
    int second = atoi(&command[2]);
    int third = atoi(&command[4]);
    
    /*
    bleSerial.print(first);
    bleSerial.print(second);
    bleSerial.println(third);
    */
    
    switch (first) {
      case connectionCategory:
        switch (second) {
          case connectionValidatePassCommand: //11XXXX
            if (checkValidPass(&command[4]))
              bleSerial.print(0);
            else
              bleSerial.print(1);

            break;
          case connectionSetPassCommand: //12XXXXYYYY
            if (checkValidPass(&command[4])) {
              uint8_t newPassLength = 0;
              while (command[4+sizeof(passphrase)*2+newPassLength*2] != 0) {
                newPassLength++;
              }

              uint8_t oldPassLength = sizeof(passphrase);

              passphrase[newPassLength];
              for (uint8_t j = 0; j < newPassLength; j++) {
                passphrase[j] = atoi(&command[4+sizeof(oldPassLength)*2+j*2]);
              }

              bleSerial.print(0);
            }
            else
              bleSerial.print(1);


            break;
        }
      break;
      case securityCategory:
        switch (second) {
          case securityLockCommand: //21
            digitalWrite(shiftRegisterEnablePin, HIGH);
            shift.writeBit(lockPin, HIGH);
            delay(500);
            shift.writeBit(lockPin, LOW);
            delay(1000);
            if (third) { //received "211"
              shift.writeBit(lockPin, HIGH);
              delay(500);
              shift.writeBit(lockPin, LOW);
              delay(1000);
            }
            break;

          case securityUnlockCommand: //22
            digitalWrite(shiftRegisterEnablePin, HIGH);
            shift.writeBit(unlockPin, HIGH);
            delay(500);
            shift.writeBit(unlockPin, LOW);
            delay(1000);
            if (third) { //received "221"
              shift.writeBit(unlockPin, HIGH);
              delay(500);
              shift.writeBit(unlockPin, LOW);
              delay(1000);
            }
            break;

            case alarmCommand: //23
            digitalWrite(shiftRegisterEnablePin, HIGH);
            shift.writeBit(alarmPin, HIGH);
            delay(500);
            shift.writeBit(alarmPin, LOW);
            delay(1000);
            break;

          default:
            break;
        }
        break;
      default:
        break;
    }
  }
  digitalWrite(shiftRegisterEnablePin, LOW);
}

/*
 * ACP communication setup
 */
void acp_setup() {
  outp(0xff, PORTD);
  outp(0xC0, DDRD);
  
  pinMode(switchPin, OUTPUT);
  digitalWrite(switchPin, LOW);
  delay(500);
  acp_uart_init(ACP_UART_BAUD_SELECT); // Initialize the ACP USART
  delay(1);
}

/*
 * Playback inline control setup
 */
void inline_control_setup() {
  //Setup inline control pin
  digitalWrite(inlineControlPin, LOW);
  pinMode(inlineControlPin, OUTPUT);
}

/*
 * Setup HM-10 BLE Serial
 */
void ble_setup() {
  //Setup HM-10 BLE serial
  bleSerial.begin(9600);

  //Setup shift register
  digitalWrite(shiftRegisterEnablePin, LOW);
  pinMode(shiftRegisterEnablePin, OUTPUT);
  shift.setBitCount(8);
  shift.setPins(16, 14, 15); //data,clock,latch
  shift.batchWriteBegin();
  //Set all shift register bits to 0
  for (uint8_t i = 0; i < 8; i++)
    shift.writeBit(i, LOW);
  shift.batchWriteEnd();
}

/*
 * Setup remote lock/unlock by BLE.
 */
void remote_access_setup() {

  //Write default passphrase and header to EEPROM if invalid header
  if (!checkValidEEPROMHeader()) {
    writePassToEEPROM();
    writeHeaderToEEPROM();
  }

  ble_setup();
}

/*
 * Simulate inline control based on value of lastCommand.
 */
void inline_control_handler() {
  //The shortest duration of digitalWrite that is sensed by iPhone SE is ~60ms.
  if (lastCommand != noCommand) {
    digitalWrite(inlineControlPin, LOW);
    switch(lastCommand) {
      case playPause:
        digitalWrite(inlineControlPin, HIGH);
        delay(100);
        digitalWrite(inlineControlPin, LOW);
        break;
      case nextTrack:
        digitalWrite(inlineControlPin, HIGH);
        delay(100);
        digitalWrite(inlineControlPin, LOW);
        delay(100);
        digitalWrite(inlineControlPin, HIGH);
        delay(100);
        digitalWrite(inlineControlPin, LOW);
        break;
      case prevTrack:
        digitalWrite(inlineControlPin, HIGH);
        delay(100);
        digitalWrite(inlineControlPin, LOW);
        delay(100);
        digitalWrite(inlineControlPin, HIGH);
        delay(100);
        digitalWrite(inlineControlPin, LOW);
        delay(100);
        digitalWrite(inlineControlPin, HIGH);
        delay(100);
        digitalWrite(inlineControlPin, LOW);
        break;
      case fastForwardTrack:
        digitalWrite(inlineControlPin, HIGH);
        delay(100);
        digitalWrite(inlineControlPin, LOW);
        delay(100);
        digitalWrite(inlineControlPin, HIGH);
        break;
      case rewindTrack:
        digitalWrite(inlineControlPin, HIGH);
        delay(100);
        digitalWrite(inlineControlPin, LOW);
        delay(100);
        digitalWrite(inlineControlPin, HIGH);
        delay(100);
        digitalWrite(inlineControlPin, LOW);
        delay(100);
        digitalWrite(inlineControlPin, HIGH);
        break;
      case activateSiri:
        digitalWrite(inlineControlPin, HIGH);
        delay(2000);
        digitalWrite(inlineControlPin, LOW);
        break;
    }
    lastCommand = noCommand;
  }
}

void setup(){
  acp_setup();
  
  inline_control_setup();

  remote_access_setup();
}

void loop()
{
  //Handle ACP communication
  acp_handler();
  
  //Handle inline control
  inline_control_handler();
  
  //Check for BLE commands
  checkBLECharacteristic();
  delay(100);
}

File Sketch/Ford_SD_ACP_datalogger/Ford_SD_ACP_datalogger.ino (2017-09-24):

//SD data logging
#include <SPI.h>
#include <SD.h>
//#include "libraries/SD/src/SD.h" //Modified SD library with all Serial functions removed. SerialPrint_P() in utility/SdFatUtil.h becomes empty.
const int chipSelect = 10;

//Ford ACP
#include <util/delay.h>
#include <TimerOne.h>
typedef unsigned char u08;
typedef unsigned short u16;
typedef unsigned long  u32;

#ifndef cbi // "clear bit"
 #define cbi(sfr, bit) (_SFR_BYTE(sfr) &= ~_BV(bit))
#endif
#ifndef sbi // "set bit"
 #define sbi(sfr, bit) (_SFR_BYTE(sfr) |= _BV(bit))
#endif
#define outp(VAL,ADRESS) ((ADRESS) = (VAL))
#define inp(VAL) (VAL)

#define ACP_UART_BAUD_RATE 	9600
#define ACP_UART_BAUD_SELECT ((u32)((u32)16000000/(ACP_UART_BAUD_RATE*16L)-1))
#define ACP_LISTEN 0
#define ACP_SENDACK 1
#define ACP_MSGREADY 2
#define ACP_WAITACK 3
#define ACP_SENDING 4

const uint8_t switchPin = 7; // Pin 7 connected to pins 2 & 3 (RE/DE) on MAX485

uint8_t acp_rx[12];
uint8_t acp_tx[12];
uint8_t acp_rxindex;
uint8_t acp_txindex;
u08 acp_status;
u08 acp_txsize;
u08 acp_timeout;
u08 acp_checksum;
u08 acp_retries;
u08 acp_mode;
uint16_t acp_ltimeout;
boolean rewindState = false;
boolean ffState = false;
boolean wPlayTime = false;
uint8_t currentTrack = 1;
boolean reset_timer = false;

void acp_uart_init(unsigned short baud) {
  cli();
  outp((u08)(baud >> 8), UBRR0H);
  outp((u08) baud, UBRR0L);
  sbi(UCSR0B, RXEN0); // Receiver enable
  sbi(UCSR0B, TXEN0); // Transmitter enable
  sbi(UCSR0B, RXCIE0); // RX complete interrupt enable
  cbi(UCSR0B, UDRIE0); // USART data register empty complete enable
  sbi(UCSR0B, UCSZ02); // Character size n (setting this to one enables 9-bit character data)
  sei();
}

SIGNAL(USART_RX_vect) {
  u08 eod = (inp(UCSR0B) & _BV(RXB80));
  uint8_t ch = inp(UDR0);

  if (acp_status != ACP_LISTEN) return; // ignore incoming msgs if busy processing
  if (!eod) acp_checksum += ch;
  acp_rx[acp_rxindex++] = ch;
  if (acp_rxindex > 12) acp_reset();
  else if (eod) {

    File dataFile = SD.open("acp_log.txt", FILE_WRITE);
      if (dataFile) {
        int i = 0;
        for (i = 0; i < sizeof(acp_rx)/sizeof(uint8_t); i++) {
          char buffer[3];
          int16_t expanded = (int16_t)acp_rx[i];
          itoa((int16_t)expanded, buffer, 16);

          dataFile.print(buffer);
          dataFile.print(" ");
        }

        //print milliseconds since power on
        String stringOne =  String(millis(), DEC);
        dataFile.println(stringOne);

        dataFile.close();
        return;
      }
    
    if (acp_checksum == ch) // Valid ACP message - send ack
    {
      acp_status = ACP_SENDACK;
      acp_handler();
    } else {
      acp_reset(); // Abort message
    }
  }
  return;
}

void acp_txenable(boolean enable) {
  if (enable) PORTD |= (1 << PD7); //sets a high state on pin PD7
  else PORTD &= ~(1 << PD7); //sets the low state on pin PD7
  asm volatile("nop");
}

void acp_sendack(void) {
  while (!(inp(PORTD) & 0x01)) // Wait till RX line goes high (idle)
    cbi(UCSR0B, RXCIE0);
  acp_txenable(true);
  sbi(UCSR0A, TXC0); // Set TXC to clear it!!
  cbi(UCSR0B, TXB80);
  outp(0x06, UDR0);
  while (!(inp(UCSR0A) & _BV(TXC0))); // wait till buffer clear
  acp_txenable(false);
}

void acp_reset(void) {
  acp_retries = 0;
  acp_timeout = 0;
  acp_checksum = 0;
  acp_rxindex = 0;
  acp_txindex = 0;
  acp_txsize = 0;
  acp_status = ACP_LISTEN;
}

void acp_sendmsg(void) {
  u08 i;
  while (!(inp(PORTD) & 0x01)) // Wait till RX line goes high (idle)
    cbi(UCSR0B, RXCIE0);
  acp_txenable(true);
  _delay_us(104 * 17);
  for (i = 0; i <= acp_txsize; i++) {
    while (!(inp(UCSR0A) & _BV(UDRIE0))); // wait till tx buffer empty
    cbi(UCSR0B, TXB80);
    if (i == acp_txsize) {
      sbi(UCSR0A, TXC0); // set TXC to clear it!
      sbi(UCSR0B, TXB80); // set 9th bit at end of message
    }
    outp(acp_tx[i], UDR0);
  }
  while (!(inp(UCSR0A) & _BV(TXC0))); // wait till last character tx complete
  acp_txenable(false); // switch back to rx mode immediately
  acp_status = ACP_WAITACK; // wait for ACK
  sbi(UCSR0B, RXCIE0);
}

void acp_handler() {
  if (acp_status == ACP_LISTEN) {
    if (++acp_ltimeout == 1000) acp_ltimeout = 0;
  }
  if (acp_status == ACP_SENDACK) {
    acp_sendack();
    acp_status = ACP_MSGREADY;
  } else if (acp_status == ACP_WAITACK) acp_reset(); // HU does not seem to return an ACK
  if (acp_status == ACP_MSGREADY) {
    acp_status = ACP_SENDING;
    acp_process(); // Process message
  } else if (acp_status == ACP_SENDING) {
    acp_timeout++;
    if (!acp_timeout) {
      acp_reset();
      acp_txenable(false);
    }
  }
}

void acp_process(void) {

  acp_timeout = 0;
  acp_tx[0] = 0x71; // medium/low priority
  acp_tx[1] = 0x9b;
  acp_tx[2] = 0x82; // message from "CD Changer" (bluetooth interface)
  acp_tx[3] = acp_rx[3];

  if (acp_rx[2] == 0x80) // Message from Head Unit
  {
    if (acp_rx[1] == 0x9a || acp_rx[1] == 0x9b) // CD Changer functional address
    {
      switch (acp_rx[3]) {
      case 0xC8: // Handshake 3 - CD Changer now recognized
        acp_tx[4] = acp_rx[4];
        acp_chksum_send(5);
        break;

      case 0xFC: // Handshake 2
        acp_tx[4] = acp_rx[4];
        acp_chksum_send(5);
        break;

      case 0xE0: // Handshake 1
        acp_tx[4] = 0x04;
        acp_chksum_send(5);
        break;

      case 0xFF: // Current disc status request - responses are
        acp_tx[4] = 0x00;
        // 00 - Disc OK
        // 01 - No disc in current slot
        // 02 - No discs
        // 03 - Check disc in current slot
        // 04 - Check all discs!
        acp_chksum_send(5);
        Timer1.initialize(1000000);
        Timer1.attachInterrupt(PlayTime);
        break;

      case 0x42: // [<- Tune]
        /*
        switch(callStatus){
        case false:
        callStatus = true;
        at_process(8);     // Answer Call
        break;
        case true:
        callStatus = false;
        at_process(10);    // End Call
        break;
        }
        */
        acp_chksum_send(5);

        break;
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

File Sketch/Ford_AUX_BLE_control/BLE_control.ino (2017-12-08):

/* 
 * BLE Control for Ford ACP AUX interface by Anson Liu
 *
 * Control vehicle locks through BLE.
 * Use 74HC595 latching shift register to control key fob.
 * Use HM-10 bluetooth module to communicate over BLE.
 * For best results, set AT+TYPE3 to enable auth+pair+bond.
 *
 */

#include <EEPROM.h>
#include <AltSoftSerial.h>
#include <Shifty.h>
AltSoftSerial bleSerial;
#define cdEnablePin 3

#define commandControlLength 3

#define connectionCategory 1
#define connectionValidatePassCommand 1
#define connectionSetPassCommand 2

const char eepromHeader[] = {
  1,
  6,
  3,
  8,
  7,
  6
};
char passphrase[] = { //121212
  0x31,
  0x32,
  0x31,
  0x32,
  0x31,
  0x32
};

#define securityCategory 2
#define securityLockCommand 1
#define securityUnlockCommand 2
#define securityAlarmCommand 3

#define lockoutInterval 10000
bool lockout;
unsigned long lockoutMillis;

char atSleep[] = "AT+SLEEP\r\n";

//Shift register setup
Shifty shift;
const uint8_t shiftRegisterEnablePin = 17;
const uint8_t lockPin = 0;
const uint8_t unlockPin = 1;
const uint8_t alarmPin = 2;

/*
 * Write passphrase to EEPROM. Writes one byte after the EEPROM Header. Separated from EEPROM Header by one byte of value 0x0. Ends with a byte of value 0x0.
 */
void writePassToEEPROM() {
  for (uint8_t i = 0; i < sizeof(passphrase); i++) {
    EEPROM.write(sizeof(eepromHeader)+1+i, passphrase[i]);
  }
  EEPROM.write(sizeof(eepromHeader)+sizeof(passphrase)+1, 0x00);
}

/*
 * Write EEPROM Header at beginning of EEPROM. Write 0x00 byte after header.
 */
void writeHeaderToEEPROM() {
  for (uint8_t i = 0; i < sizeof(eepromHeader); i++)
    EEPROM.write(i, eepromHeader[i]);
  EEPROM.write(sizeof(eepromHeader), 0x00);
}

/*
 * Read passphrase from EEPROM
 */
void readPassFromEEPROM() {
  for (uint8_t i = 0; i < sizeof(passphrase); i++) {
    passphrase[i] = EEPROM.read(sizeof(eepromHeader)+1+i);
  }
}

/*
 * Reset all EEPROM to 0xff (255). 0xff (255) is the default eeprom value.
 */
void resetEEPROM() {
  for (int i = 0; i < EEPROM.length(); i++) {
    EEPROM.write(i, 0xff); 
  }
}

/*
 * Check for valid EEPROM Header at beginning of EEPROM.
 */
bool checkValidEEPROMHeader() {
  for (uint8_t i = 0; i < sizeof(eepromHeader); i++) {
    if (EEPROM.read(i) != eepromHeader[i])
      return false;
  }
  return true;
}

bool checkValidPass(uint8_t* pass) {
  readPassFromEEPROM();

  if (memcmp(passphrase, pass, sizeof(passphrase)) == 0)
    return true;
  else
    return false;
}

/*
 * Check BLE Characteristic for HM-10 BLE Module and process any commands. 
 */
void checkBLECharacteristic() {
  //Determine if lockout mode for connectionCategory. Return error code 2 if lockout
  if (lockout && (unsigned long)(millis() - lockoutMillis) >= lockoutInterval)
    lockout = false;

  char command[50];
  memset(command, 0, sizeof(command));

  uint8_t cLength = 0;
  while (bleSerial.available()) {
    command[cLength] = bleSerial.read();
    cLength++;
    delay(100); //Wait for a short time ~100ms with HM-10 before checking to see if serial has data available. Checking too fast may result in loss of data (data not available yet).
  }

  if (cLength) {
    uint8_t commandControl[commandControlLength];
    for (uint8_t i = 0; i < commandControlLength; i++) {
      char buffer[1];
      buffer[0] = command[i];
      commandControl[i] = atoi(buffer);
    }

    //response buffer
    char response[5];
    memset(response, 0, sizeof(response));
    for (uint8_t i = 0; i < 3; i++) {
      response[i] = command[i];
    }

    //return if lockout mode active
    if (lockout) {
      response[3] = 0x32;
      bleSerial.print(response);
      return;
    }

    switch (commandControl[0]) {
      case connectionCategory:
        switch (commandControl[1]) {
          case connectionValidatePassCommand: //110XXXXXX (ascii)

            if (checkValidPass((uint8_t*)&command[commandControlLength])) {              
              response[3] = 0x30;
              bleSerial.print(response);
            }
            else {
              response[3] = 0x31;
              bleSerial.print(response);
              lockoutMillis = millis();
              lockout = true;
            }

            break;
          case connectionSetPassCommand: //120XXXXXXYYYYYY
          
            if (checkValidPass((uint8_t*)&command[commandControlLength])) {
              for (uint8_t i = 0; i < sizeof(passphrase); i++) {
                passphrase[i] = command[commandControlLength+sizeof(passphrase)+i];
              }
              writePassToEEPROM();
              response[3] = 0x30;
              bleSerial.print(response);
            } else {
              response[3] = 0x31;
              bleSerial.print(response);
              lockoutMillis = millis();
              lockout = true;
            }


            break;
        }
      break;
      case securityCategory:
        switch (commandControl[1]) {
          case securityLockCommand: //210XXXXXX
            if (checkValidPass((uint8_t*)&command[commandControlLength])) {
              
              digitalWrite(shiftRegisterEnablePin, HIGH);
              shift.writeBit(lockPin, HIGH);
              delay(500);
              shift.writeBit(lockPin, LOW);
              delay(1000);

              if (commandControl[2]) { //221XXXXXX
                shift.writeBit(lockPin, HIGH);
                delay(500);
                shift.writeBit(lockPin, LOW);
                delay(1000);
              }
              response[3] = 0x30;
              bleSerial.print(response);
            }
            else {
              response[3] = 0x31;
              bleSerial.print(response);
            }
            break;
          case securityUnlockCommand: //220XXXXXX
            if (checkValidPass((uint8_t*)&command[commandControlLength])) {

              digitalWrite(shiftRegisterEnablePin, HIGH);
              shift.writeBit(unlockPin, HIGH);
              delay(500);
              shift.writeBit(unlockPin, LOW);
              delay(1000);

              if (commandControl[2]) { //221XXXXXX
                shift.writeBit(unlockPin, HIGH);
                delay(500);
                shift.writeBit(unlockPin, LOW);
                delay(1000);
              }
              response[3] = 0x30;
              bleSerial.print(response);
            }
            else {
              response[3] = 0x31;
              bleSerial.print(response);
            }
            break;
          case securityAlarmCommand: //230XXXXXX
            if (checkValidPass((uint8_t*)&command[commandControlLength])) {

              digitalWrite(shiftRegisterEnablePin, HIGH);
              shift.writeBit(alarmPin, HIGH);
              delay(500);
              shift.writeBit(alarmPin, LOW);
              delay(1000);
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

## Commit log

2017-05-08 add README
    [c-174045-2-c1-3d.stp, c-174051-2-k-3d.stp]
2017-08-17 lcd graphs
    [FordACPAUX.brd, FordACPAUX.sch]
2017-08-29 ford ble control in progress
    [liu_acp_datalog.xlsx]
2017-09-17 add BOM
    [BOM.xlsx, LIU_FORD_ACP_AUX_BOM.xlsx]
2017-09-24 Add directory for SD datalogging RX only sketch Fixed minutes:seconds play time display in ACP.ino Ford_AUX_BLE_control sketch (latest branch
    [ACP.ino, CD.ino, Ford_SD_ACP_datalogger.ino]
2017-09-25 change minutes:seconds variable to uint8_t to prevent overflow in acp_tx array
    [ACP.ino]

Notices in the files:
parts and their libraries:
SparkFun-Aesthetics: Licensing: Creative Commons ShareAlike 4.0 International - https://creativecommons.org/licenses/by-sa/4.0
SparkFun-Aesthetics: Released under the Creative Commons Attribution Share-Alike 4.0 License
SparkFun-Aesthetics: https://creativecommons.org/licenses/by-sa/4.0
